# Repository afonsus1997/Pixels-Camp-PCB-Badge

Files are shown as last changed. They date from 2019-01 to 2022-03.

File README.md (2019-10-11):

# Pixels Camp PCB Badge

Working!

## Info
This is a PCB badge for the 2019 edition of pixels camp. The project consists on a 39x9 (351) LED matrix display driven by the IS31FL3741 IC and controlled by an ESP32, making it wifi-connected. The board can be powered by usb and/or a 1s lipo battery (charges with usb).

The main goal is to make a web connected scrolling text display, although anyone can develop a custom version of the firmware.

## Sponsors
ISSI
PCBway

#### PCBWay
PCBWay was kind enough to supply the V2.1 Pcbs and stencils.

#### ISSI
IssI has been a great supporter due to it's technical support and the supplied some samples of the driver IC and the corresponding devboard.

**I thank both of the sponsors for making the new version possible!**

## Updates

### Latest Updates
* New version in development
	* Waiting for the new PCBs and components to arrive 

### Known Bugs
* Waiting for the new version

### TODO
* Assemble new board

## Circuit and PCB

### Circuit

#### Schematics
All Schematics can be found in the PDF folder of the PCB Project
*   [PDFs Folder](https://github.com/afonsus1997/Pixels-Camp-PCB-Badge/tree/master/PCB%20ESP32/PDF)
	* [Control Board Schematic](https://github.com/afonsus1997/Pixels-Camp-PCB-Badge/blob/master/PCB%20ESP32/PDF/CONTROL/Schematic.PDF)   
	* [Matrix Schematic](https://github.com/afonsus1997/Pixels-Camp-PCB-Badge/blob/master/PCB%20ESP32/PDF/MATRIX/Schematic.PDF) 	

#### Power
Power is supplied by usb and/or 1s lipo, with usb charging capabilities.

Circuit

The circuit can be powered by usb and/or 1s lipo. T1 is disabled when usb is present and vice-versa. There is also a main power switch that toggles T2.
An LTSpice simulation is present in the [Simulations](https://github.com/afonsus1997/Pixels-Camp-PCB-Badge/tree/master/PCB%20ESP32/Simulations) folder.

Used ICs:
* Voltage Regulator: NCP708
    * [Datasheet](https://www.onsemi.com/pub/Collateral/NCP708-D.PDF)
* Lipo charger: MCP73831T-2ADI/OT
    * [Datasheet](https://www.sparkfun.com/datasheets/Prototyping/Batteries/MCP73831T.pdf)

#### Digital and logic
The microcontroller used is the ESP32 with WIFI and bluetooth built-in. The LED matrix is driven by the IS31FL3741 IC. The usb to serial conversion in handled by the CH340G (with auto-reset DTR capabilities).

Used ICs:
* uC: ESP32
    * [Datasheet](https://www.espressif.com/sites/default/files/documentation/esp32_datasheet_en.pdf)
* USB-to-Serial: CH340G
    * [Datasheet](https://cdn.sparkfun.com/datasheets/Dev/Arduino/Other/CH340DS1.PDF)
* LED driver: IS31FL3741
    * [Datasheet](http://ams.issi.com/WW/pdf/IS31FL3741.pdf)
    * [Dev Board](http://ams.issi.com/WW/pdf/IS31FL3741_EB.pdf)

### PCBs
The PCBs was designed in Altium Designer and the most recent GERBERs and schematics are available in their respective repo folders. The Badge consists of 2 stackable PCBs, one for the matrix and one for the power and logic. Each PCB is 126x36mm and there is a panel PCB with both of the PCBs held by cuttable tabs. The panel is 140x91mm.

#### IO
Placeholder

#### Renders

##### 2D 
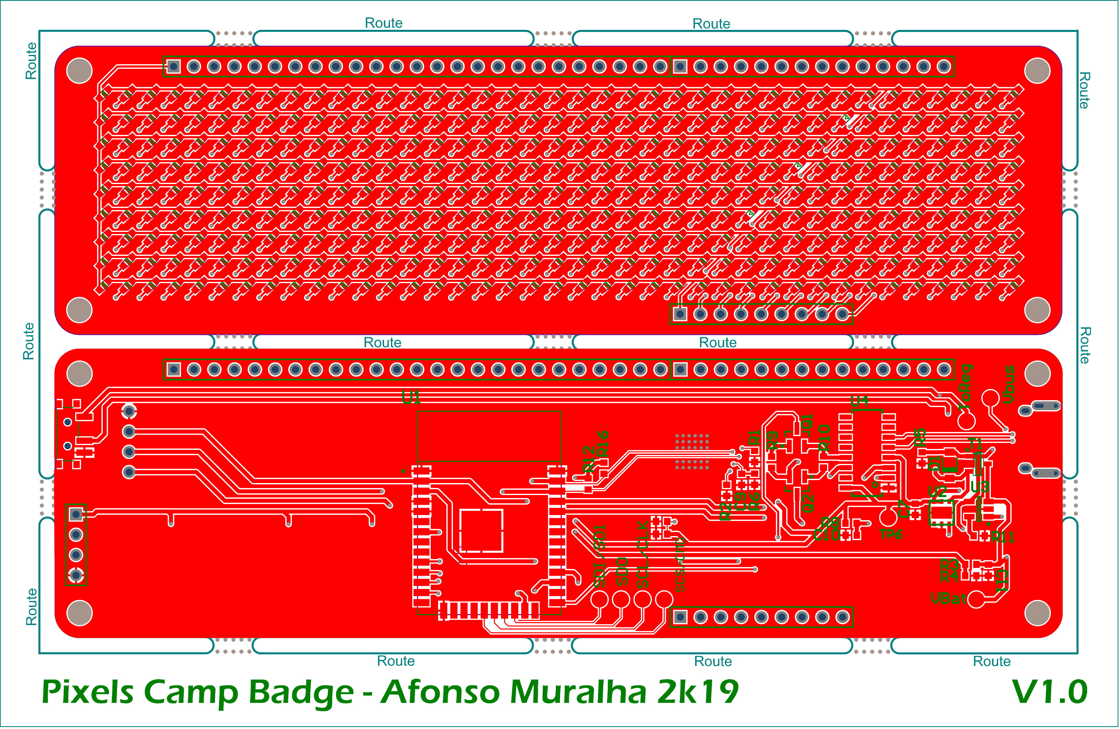
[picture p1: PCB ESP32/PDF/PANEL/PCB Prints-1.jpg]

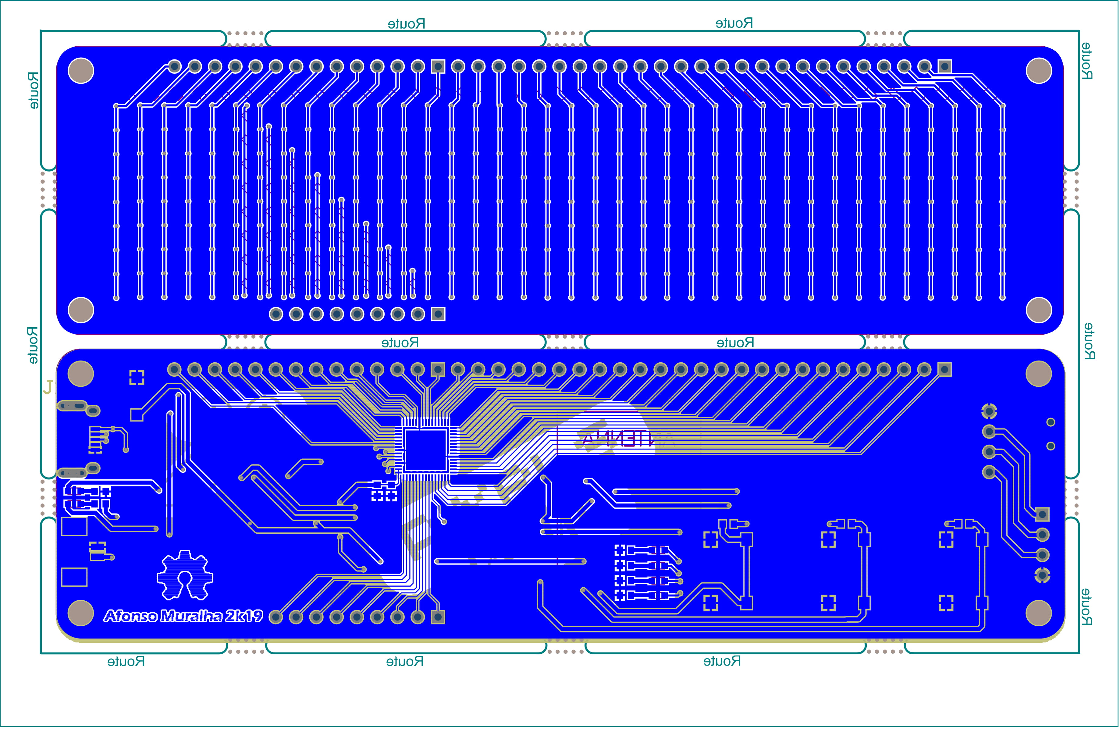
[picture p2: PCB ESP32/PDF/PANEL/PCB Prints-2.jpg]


##### 3D
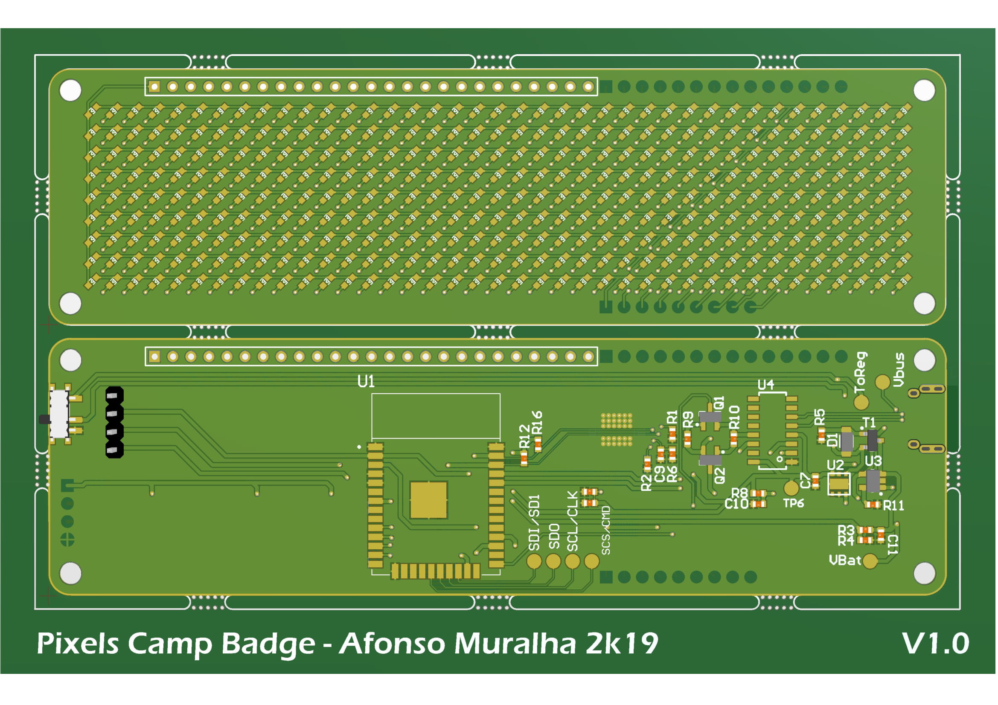
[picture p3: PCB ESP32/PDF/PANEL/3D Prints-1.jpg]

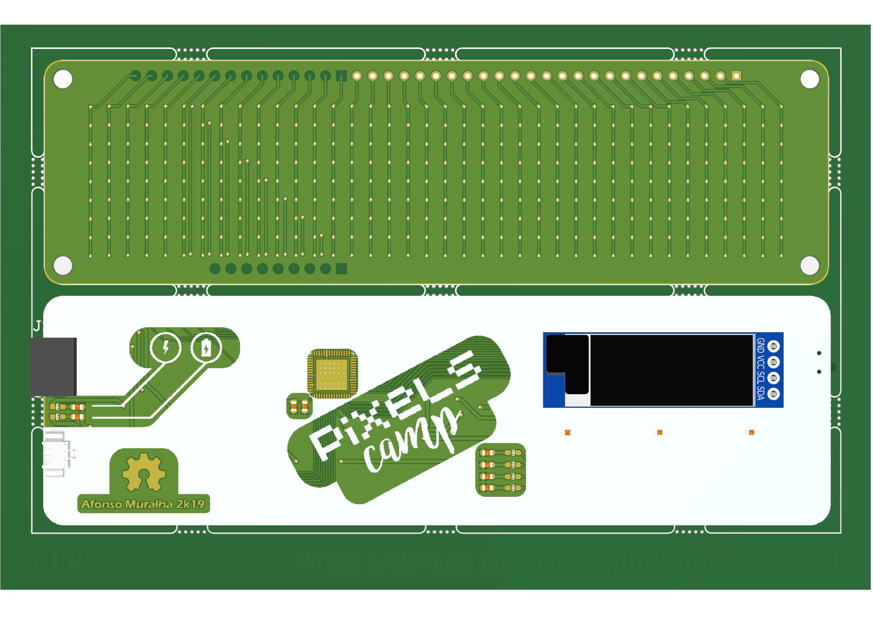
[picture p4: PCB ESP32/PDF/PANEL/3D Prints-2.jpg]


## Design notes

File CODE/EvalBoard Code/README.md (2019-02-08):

# Pixels Camp PCB Badge

## Info
This is a PCB badge for the 2019 edition of pixels camp. The project consists on a 39x9 (351) LED matrix display driven by the IS31FL3741 IC and controlled by an ESP32, making it wifi-connected. The board can be powered by usb and/or a 1s lipo battery (charges with usb).

The main goal is to make a web connected scrolling text display, although anyone can develop a custom version of the firmware.

**Special thanks to ISSI for supporting the project by supplying a devboard for the IS31FL3741 IC, much apreciated!**

## Updates

### Latest Updates
* Working on the firmware (freeRTOS?)
* Working on new control board design

### Known Bugs
* Swapped pins on the regulator footprint
    * Fixed in new version (added an aditional regulator)
* USB-to-Serial (CH340G) needs external oscillator

### TODO
* Fix bugs
* (Add a boot switch for convinience)
* Test LED Matrix with devboard

## Circuit and PCB

### Circuit

#### Power
Power is supplied by usb and/or 1s lipo, with usb charging capabilities.

Circuit

The circuit can be powered by usb and/or 1s lipo. T1 is disabled when usb is present and vice-versa. There is also a main power switch that toggles T2.
An LTSpice simulation is present in the [Simulations](https://github.com/afonsus1997/Pixels-Camp-PCB-Badge/tree/master/PCB%20ESP32/Simulations) folder.

Used ICs:
* Voltage Regulator: NCP708
    * [Datasheet](https://www.onsemi.com/pub/Collateral/NCP708-D.PDF)
* Lipo charger: MCP73831T-2ADI/OT
    * [Datasheet](https://www.sparkfun.com/datasheets/Prototyping/Batteries/MCP73831T.pdf)

#### Digital and logic
The microcontroller used is the ESP32 with WIFI and bluetooth built-in. The LED matrix is driven by the IS31FL3741 IC. The usb to serial conversion in handled by the CH340G (with auto-reset DTR capabilities).

Used ICs:
* uC: ESP32
    * [Datasheet](https://www.espressif.com/sites/default/files/documentation/esp32_datasheet_en.pdf)
* USB-to-Serial: CH340G
    * [Datasheet](https://cdn.sparkfun.com/datasheets/Dev/Arduino/Other/CH340DS1.PDF)
* LED driver: IS31FL3741
    * [Datasheet](http://ams.issi.com/WW/pdf/IS31FL3741.pdf)
    * [Dev Board](http://ams.issi.com/WW/pdf/IS31FL3741_EB.pdf)

### PCBs
The PCBs was designed in Altium Designer and the most recent GERBERs and schematics are available in their respective repo folders. The Badge consists of 2 stackable PCBs, one for the matrix and one for the power and logic. Each PCB is 126x36mm and there is a panel PCB with both of the PCBs held by cuttable tabs. The panel is 140x91mm.

#### IO
Placeholder

#### Renders

##### 2D 
TOP
BOT

##### 3D
TOP
BOT

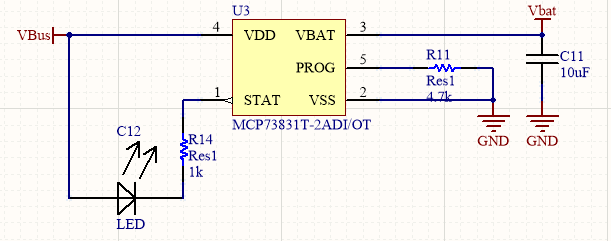
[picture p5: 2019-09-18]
Blog Writeup/Pictures/chargingschematic.PNG

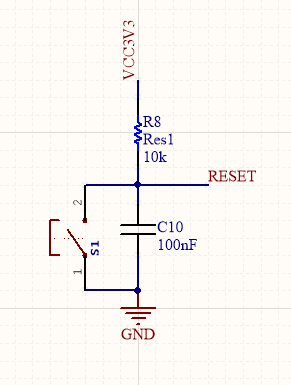
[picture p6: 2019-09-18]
Blog Writeup/Pictures/esp32reset_schematic.PNG

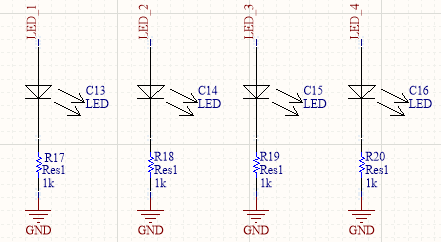
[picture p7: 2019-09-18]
Blog Writeup/Pictures/esp32led_schematic.PNG

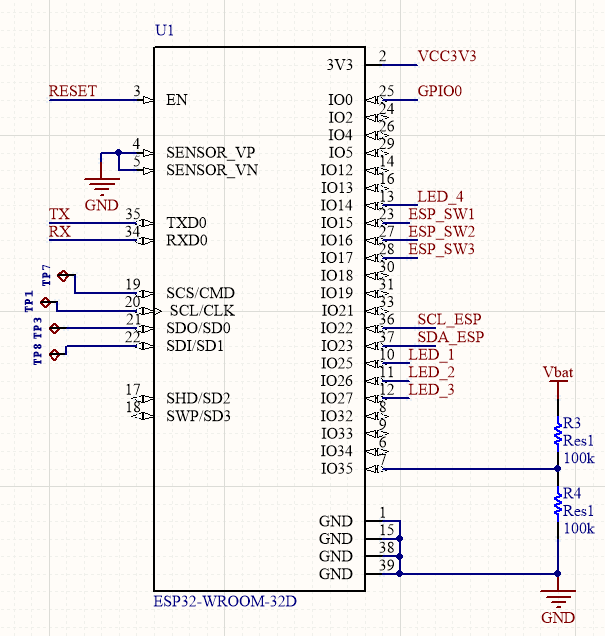
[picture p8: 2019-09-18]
Blog Writeup/Pictures/esp32_schematic.PNG

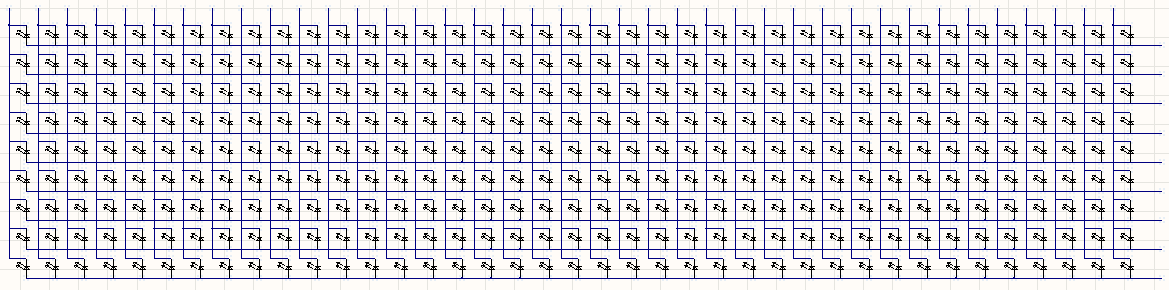
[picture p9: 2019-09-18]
Blog Writeup/Pictures/Ledmatrix_schematicc.PNG

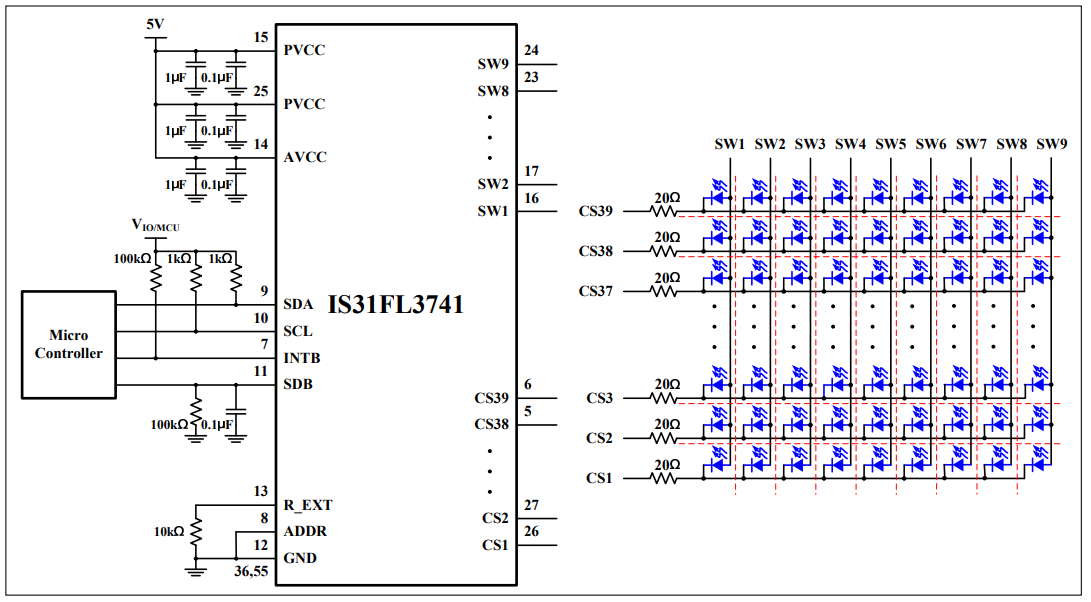
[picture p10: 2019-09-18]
Blog Writeup/Pictures/issisamplecircuit.PNG

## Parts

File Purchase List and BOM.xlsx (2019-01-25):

Purchase List |  |  |  |  |  | BOM
PCB
Product | Store | Quantity |  |  | Price
PCB Panel | JLC PCB | 5 |  |  | 20.76
Total |  |  |  |  | 20.76
Components |  |  |  |  |  | Components
Product | Store | Quantity | Used | Remaining | Price | Component type | Product | Available | Required | Price per part | Price
MMBT2222A-7-F (NPN Transistor) | Arrow | 6 | 0 | 6 | 0.58 | NPN Transistor | MMBT2222A | 6 | 2 | 0.09666666667 | 0.1933333333
NCP708MU330TAG (3v3 Regulator) | Arrow | 5 | 1 | 4 | 1.74 | 3.3V Regulator | NCP708MU330TAG | 4 | 1 | 0.348 | 0.348
B5818W (schottky diode) | Arrow | 5 | 0 | 5 | 0.36 | Schottky Diode |  | 105 | 1
MCP73831T (lipo charger) | Arrow | 2 | 0 | 2 | 0.89 |  | B5818W | 5 |  | 0.072 | 0.072
 | Ali | 10 | 0 | 10 | 1 |  | IN5817 | 100 |  | 0.0094 | 0.0094
DMP2045U (p-channel mosfet) | Arrow | 2 | 0 | 2 | 0.68 | Lipo Charger | MCP73831T | 12 | 1 | 0.1 | 0.1
532610271 (lipo connector) | Arrow | 2 | 0 | 2 | 1.4 | P-channel MOSFET |  | 72 | 1
 | Ali | 10 | 0 | 10 | 0.7 |  | DMP2045U | 2 |  | 0.34 | 0.34
tax | Arrow | 1 | 0 | 1 | 1.19 |  | AO3407 | 50 |  | 0.0212 | 0.0212
IS31FL3741-QFLS4-TR (LED driver) | Arrow | 2 | 0 | 2 | 4.8 |  | DMG3415U | 20 |  | 0.0925 | 0.0925
1054431101 (USB connector) | Arrow | 2 | 0 | 2 | 1.48 | Lipo Connector | 532610271 | 12 | 1 | 0.07 | 0.07
tax | Arrow | 1 | 0 | 1 | 1.01 | LED Driver | IS31FL3741 | 2 | 1 | 2.4 | 2.4
AO3407 (p-channel mosfet) | Ali | 50 | 0 | 50 | 1.06 | USB Connector | USB connector 1 | 20 | 1 | 0.035 | 0.035
DMG3415U (p-channel mosfet) | Ali | 20 | 0 | 20 | 1.85 | Green LED | 0603 LED | 1000 | 351 | 0.00396 | 1.38996
IN5817 (schottky diode) | Ali | 100 | 0 | 100 | 0.94 | ESP32 | ESP32 | 3 | 1 | 3.333333333 | 3.333333333
Green LED | Ali | 1000 | 0 | 1000 | 3.96 | Lipo Cable | Lipo Cable | 10 | 1 | 0.088 | 0.088
ESP32 | Ali | 3 | 0 | 3 | 10 | USB to Serial | CH340G | 5 | 1 | 0.268 | 0.268
Lipo Cable | Ali | 10 | 0 | 10 | 0.88 | Push Button | Push Button | 50 | 3 | 0.015 | 0.045
CH340G (USB to Serial) | Ali | 5 | 0 | 5 | 1.34 | PCB | PCB | 5 | 1 | 4.152 | 4.152
Push button | Ali | 50 | 0 | 50 | 0.75
USB connector 1 | Ali | 20 | 0 | 20 | 0.7 | Total |  |  |  |  | 12.35322667
USB connector 2 | Ali | 10 | 0 | 10 | 0.5
Total |  |  |  |  | 37.81
Total (all) |  |  |  |  | 58.57

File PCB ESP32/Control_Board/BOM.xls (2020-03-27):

Comment | Value | Description | Designator | Footprint | LibRef | Quantity
Footprint of the VIMEX MSK-12C02 SPDT SMD Switch Created by mzst on 17-Jan-2016 |  |  | 1 | MSK-12C02 | MSK-12C02_SMD_SPDT_SWITCH | 1
AMS1117 |  | LDO 3.3V/5V/12V | AMS1 | SOT-223-3 | AMS1117 | 1
10uF |  |  | C1, C3, C13 | C 0603 / 1608 | Capacitor | 3
1uF |  |  | C2, C4, C6, C8 | C 0603 / 1608 | Capacitor | 4
0.1uF |  |  | C5, C7, C11 | C 0603 / 1608 | Capacitor | 3
22uF |  |  | C9 | C 0603 / 1608 | Capacitor | 1
LED |  |  | C10, C14, C15, C16, C17, C18 | LED 0603(2) | LED | 6
100nF |  |  | C12 | C 0603 / 1608 | Capacitor | 1
Diode_Littelfuse_SP0503BAHTG_eec |  | DIODE TVS DIODE 5.5VWM 8.5VC SOT143 | D1 | Littelfuse_SP0503BAHTG_0 | Diode_Littelfuse_SP0503BAHTG_eec | 1
B5819W |  | Schottky Barrier Rectifier, 1 A, 40 Vrm, -65 to 125 degC, 2-Pin SOD123, RoHS, Tape and Reel | D2, D3 | MCC-SOD123_V | CMP-2100-03587-1 | 2
MicroUsb |  | 10103594-0001LF Conn Micro USB Type B RCP 5 POS 0.65mm Solder RA SMD 5 Terminal 1 Port T/R | J1 | USB-MicroB | MicroUsb | 1
53261-0271 |  | PicoBlade(TM) Header, Right Angle, -40 to 85 degC, 2-Pin SMD, RoHS, Tape and Reel | P1 | MOLX-53261-0271_V | CMP-2000-05633-1 | 1
Header 5X2 |  | Header, 5-Pin, Dual row | P2 | 5x2_SidePCB | Header 5X2 | 1
Header 3X2 |  | Header, 3-Pin, Dual row | P3 | 3x2_SidePCB | Header 3X2 | 1
Header 25 |  | Header, 25-Pin | P4 | HDR1X25 | Header 25 | 1
Header 4 |  | Header, 4-Pin | P5 | HDR1X4 | Header 4 | 1
Header 14 |  | Header, 14-Pin | P6 | HDR1X14 | Header 14 | 1
Header 9 |  | Header, 9-Pin | P7 | HDR1X9 | Header 9 | 1
MMBT2222LT1G |  | General Purpose Transistor, NPN, 0.6 A IC Continuous, 3-Pin SOT23, RoHS, Tape and Reel | Q1, Q2 | ONSC-SOT-23-3-318-08_M | CMP-0722-00001-1 | 2
Res1 | OPEN | Resistor | R1, R2, R5, R8, R10, R17, R30, R32 | C 0603 / 1608 | Res1 | 8
Res1 | 470 | Resistor | R3, R4 | C 0603 / 1608 | Res1 | 2
Res1 | 100k | Resistor | R6, R7, R9, R16 | C 0603 / 1608 | Res1 | 4
Res1 | 10k | Resistor | R11, R12, R13, R15, R18, R21, R22, R23 | C 0603 / 1608 | Res1 | 8
Res1 | 1k | Resistor | R14, R20, R26, R27, R28, R29 | C 0603 / 1608 | Res1 | 6
Res1 | 4.7k | Resistor | R19, R24, R25, R31 | C 0603 / 1608 | Res1 | 4
742C083121JP |  | Res Thick Film Array 120 Ohm 5% 1/4W Â±200ppm/Â°C ISOL Molded 8-Pin 1206_4 X 0603_ Concave SMD Paper T/R | RN1, RN2, RN3, RN4, RN5, RN6, RN7, RN8, RN9, RN10 | RESARRAY(4x0603) | Resistor Array 4x | 10
Switch |  |  | S1 | PUSH_SMD_3x4 | B3U-1000P | 1
DTSM-6 |  |  | S2, S3, S4 | DTSM-6 | DTSM-6 | 3
DMP2045U |  | P-CHANNEL MOSFET WITH DIODE | T1, T2 | SOT95P237X112-3N | Si2333CDS-T1-GE3 | 2
Test pad |  |  | ToReg1, TP1, VBat1, VBus1 | TP20R | TPTP20R | 4
ESP32-WROOM-32D |  | IC: SoC; GPIO, I2C, I2S, IR, SD, SDIO, SPI, UART; 2.7Ã·3.6VDC; 20dBm | U1 | MODULE_ESP32-WROOM-32D | ESP32-WROOM-32D | 1
CP2102-GM | Value | No Description Available | U2 | QFN28_5X5 | CP2102-GM | 1
IS31FL3741 |  |  | U3 | QFN40P700X700X80-61N | IS31FL3741 | 1
MCP73831T-2ADI/OT |  | Miniature Single-Cell, Fully Integrated Li-Ion, Li-Polymer Charge Management Controller, 4.2V, 5-Pin SOT-23, Industrial Temperature, Tape and Reel | U4 | SOT-23-OT5_M | CMP-0133-00142-1 | 1

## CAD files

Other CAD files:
PCB ESP32/Media/Control/bot_silkV2.dxf

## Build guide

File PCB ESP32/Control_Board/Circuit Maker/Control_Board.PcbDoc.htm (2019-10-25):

Reporting Options

# File in Previous Format

Date | : | 19/10/2019
Time | : | 12:14:36
Filename | : | F:\Documents\GitHub\0603-Led-Matrix\PCB ESP32\Control_Board\Circuit Maker\Control_Board.PcbDoc

Version | Warning
6.3 | CAUTION - Via connections to both hatched and solid signal layer polygons are now controlled by the polygon connect style rule. Re-pouring polygons may result in physical copper differences.
Summer 09 | CAUTION - File contains old violation objects. These violations are no longer supported & will not be loaded. Please run DRC after opening this file in order to refresh the violations.
Summer 09 | CAUTION - Existing testpoint rules and settings are used as fabrication testpoint information.
Altium Designer update 19 | CAUTION - Air Gap Width attribute was introduced to Polygon Connect Style Rule. Air Gap Width attribute now controls the distance between poured polygon and pads on the same net - this value was previosuly taken from clearance rule while ignoring net subscope leading to sometime unexpected results.
Release 13 | CAUTION - Silkscreen Over Component Pads Rules are converted to Silk To Solder Mask Clearance Rules. Suggest examining rule scopes for accuracy.
Release 14 | CAUTION - The Differential Pairs Routing rule added support for control of the width. Be aware that Width rules pertaining to differential pairs need to be manually moved to the Differential Pairs Routing rule.

This file was generated by an earlier version of the software

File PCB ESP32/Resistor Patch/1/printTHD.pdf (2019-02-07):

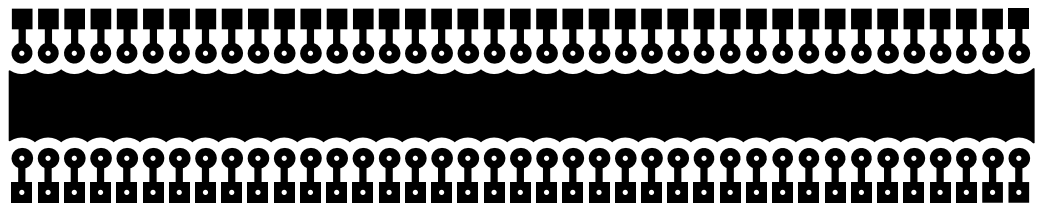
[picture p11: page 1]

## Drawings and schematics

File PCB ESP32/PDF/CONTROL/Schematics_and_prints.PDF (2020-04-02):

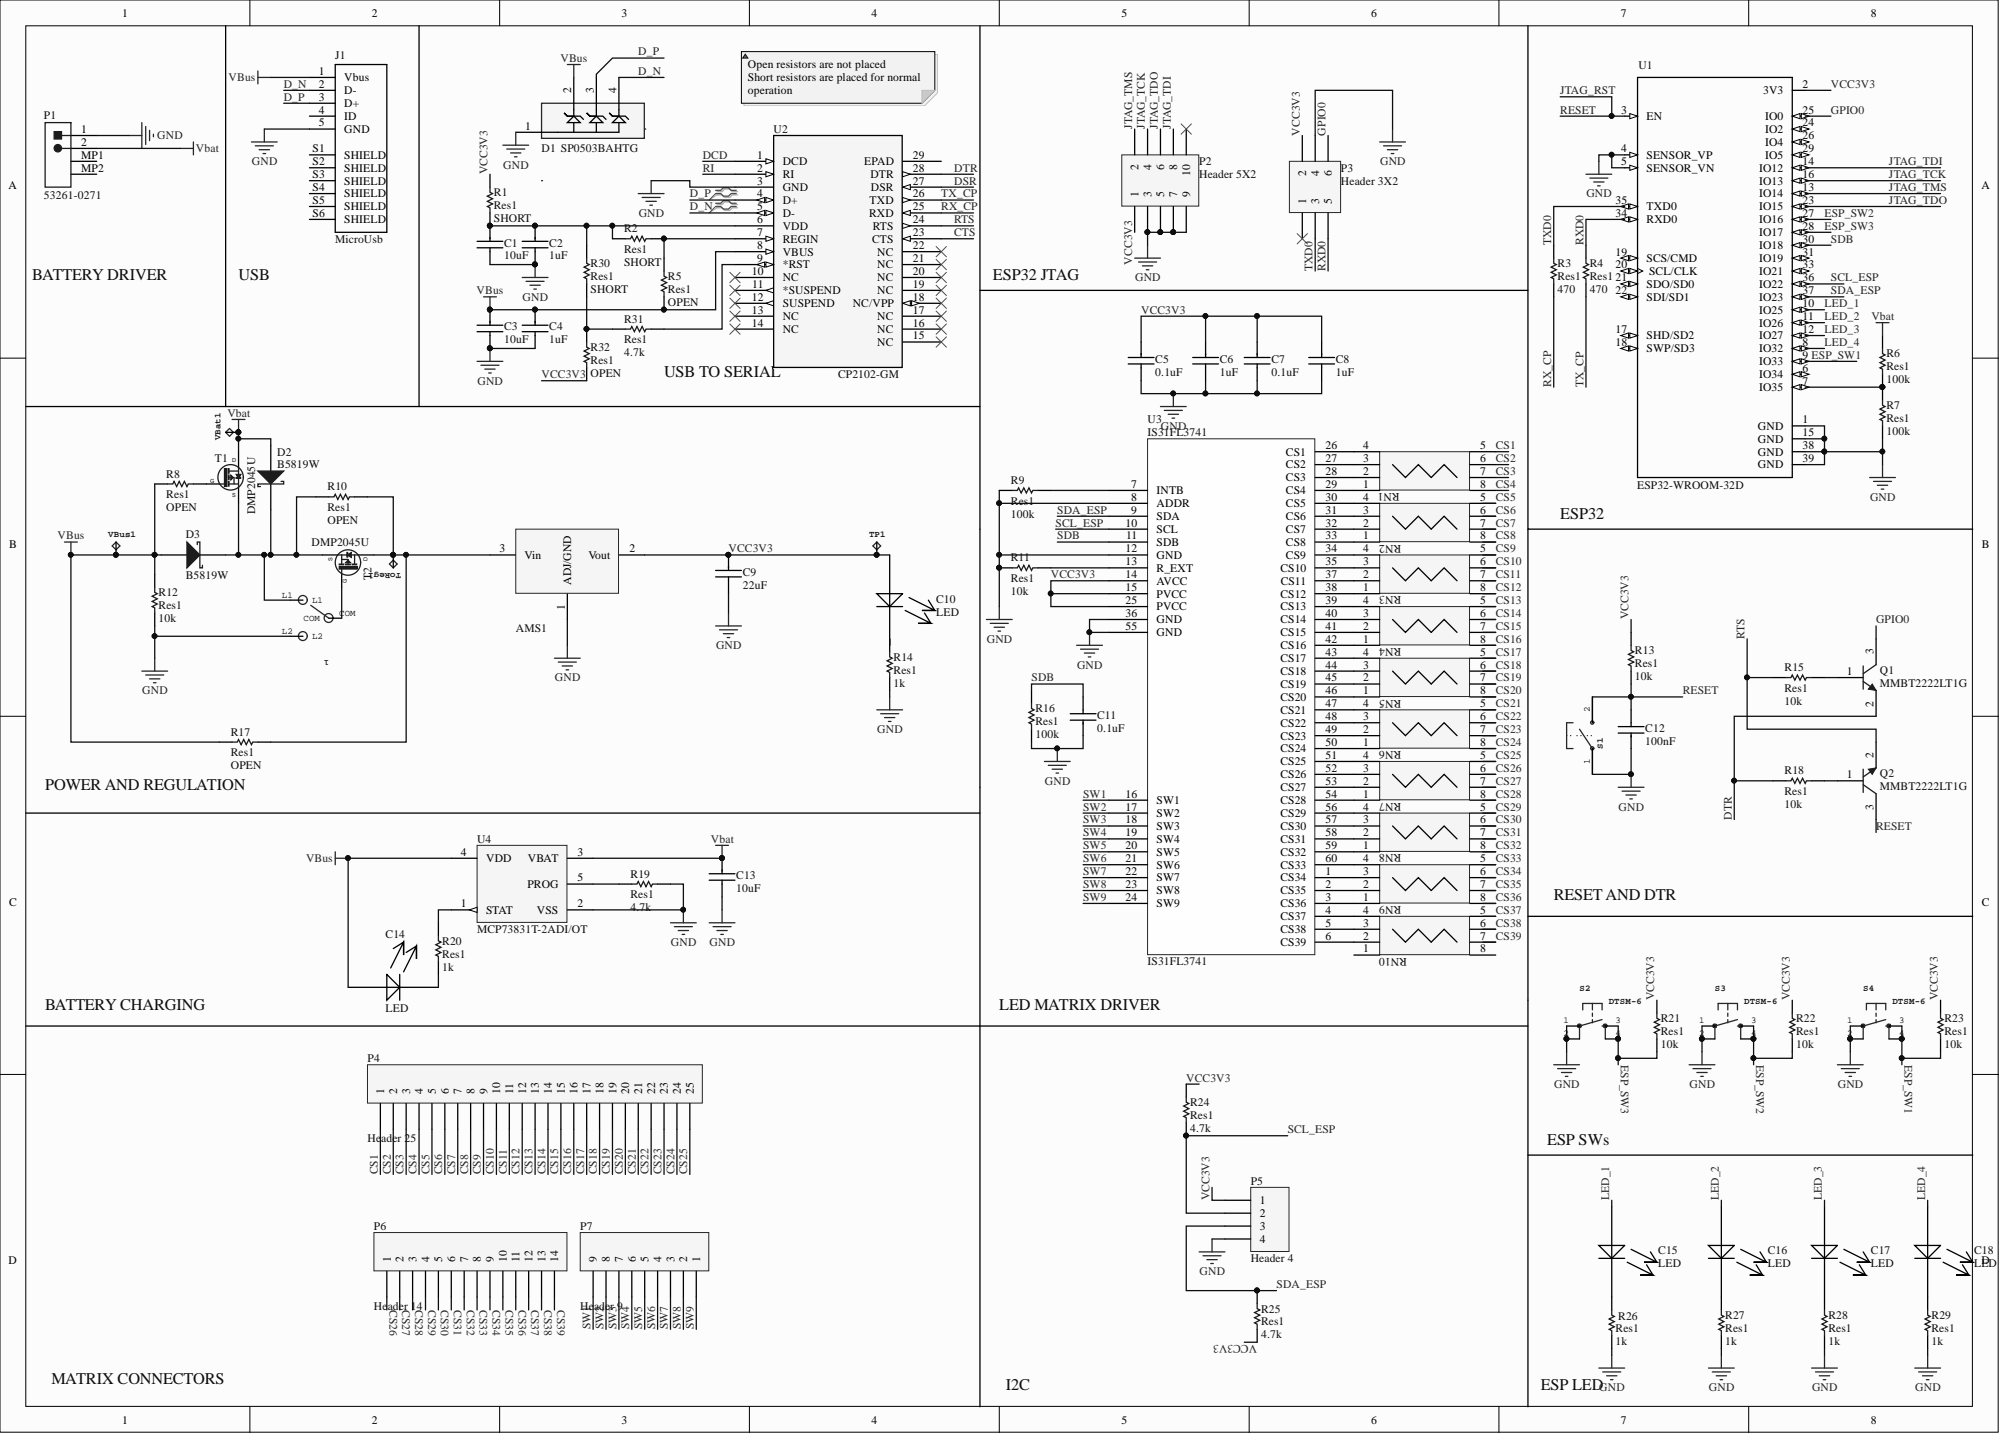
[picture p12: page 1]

Open resistors are not placed
Short resistors are placed for normal
operation

REGIN 7
VBUS 8
*RST 9

R5 Res1 OPEN | | NC 10

PVCC 15 | 1 | | 8
PVCC 25 | 5

SDB | GND 36 | 3 | | 6

GND 55 | 2 | | 7

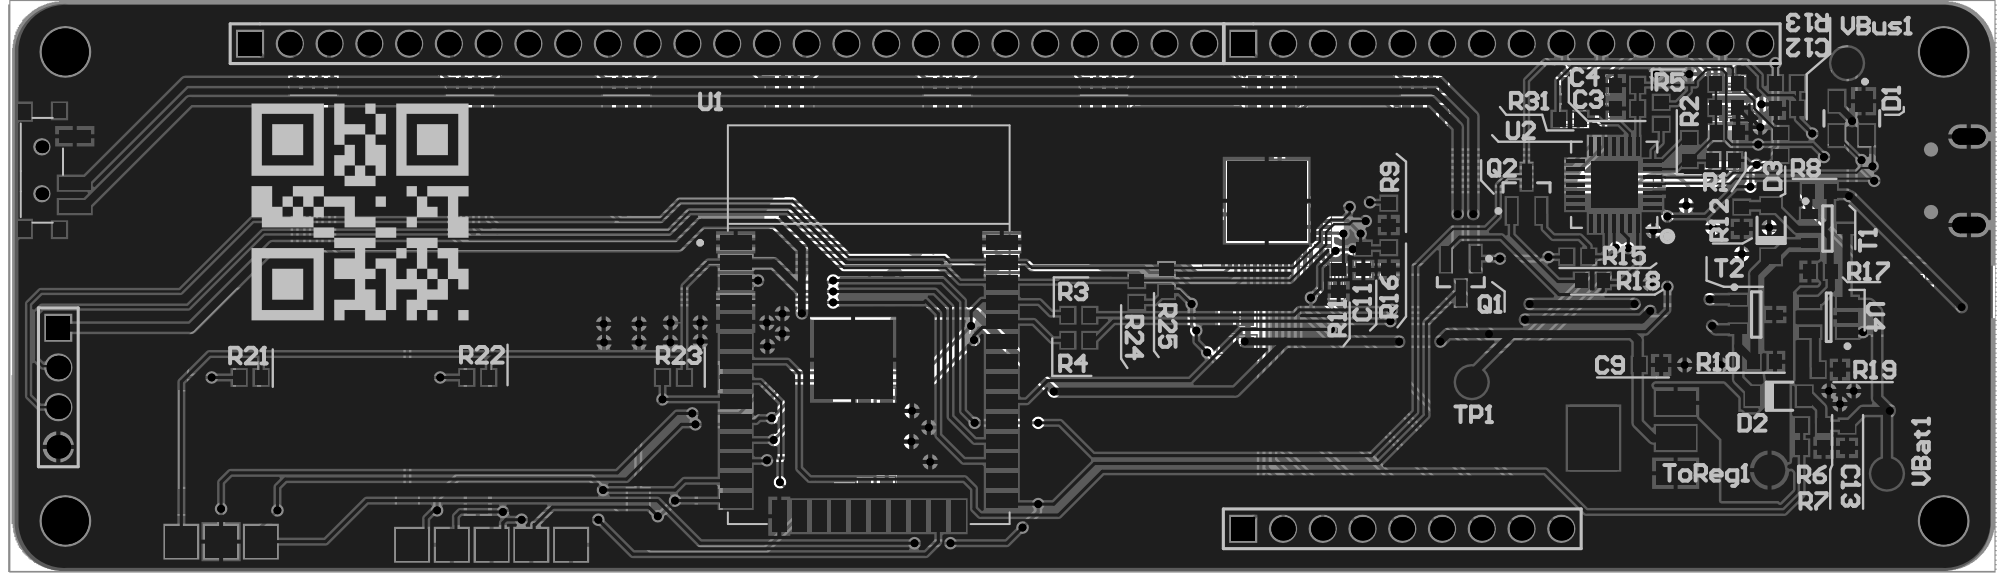
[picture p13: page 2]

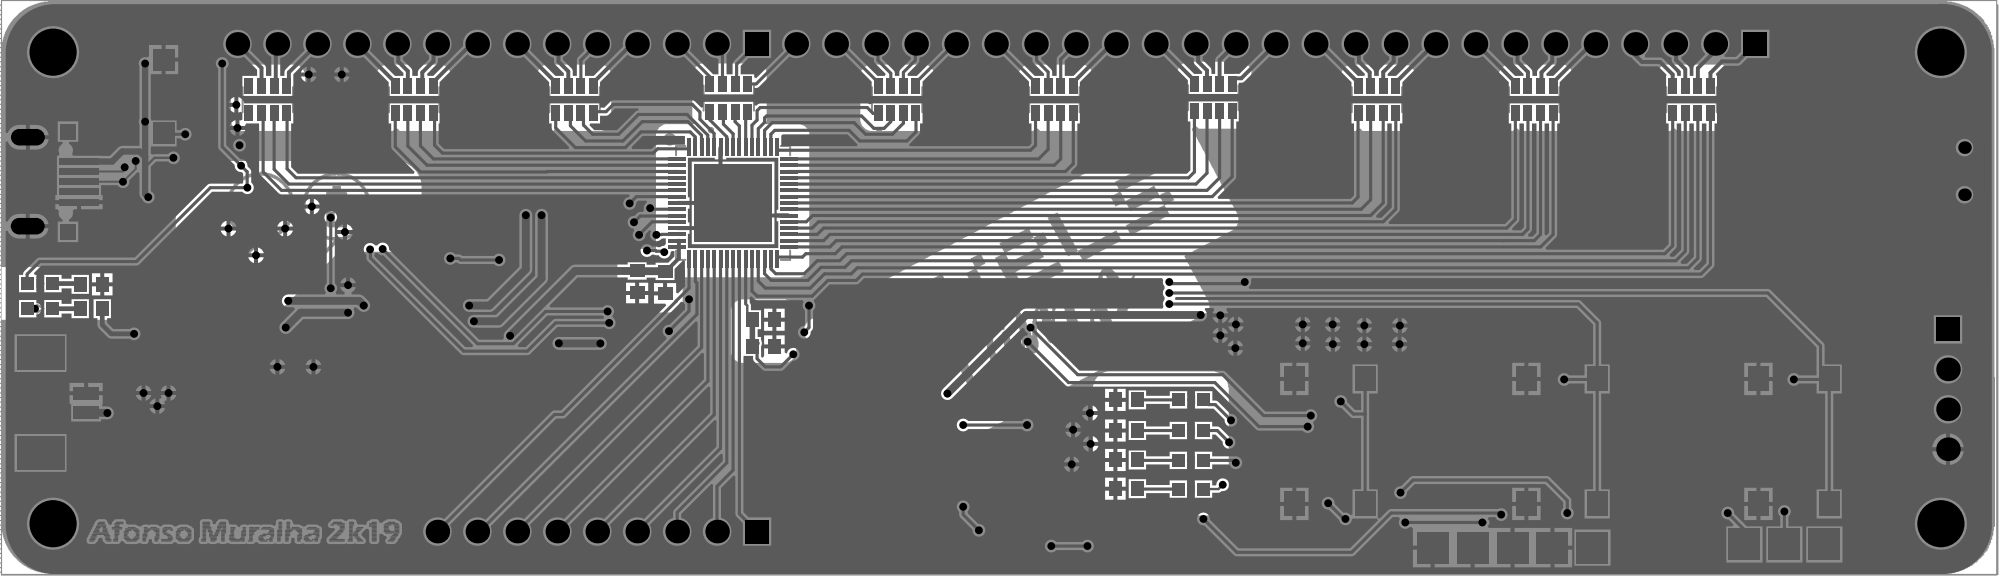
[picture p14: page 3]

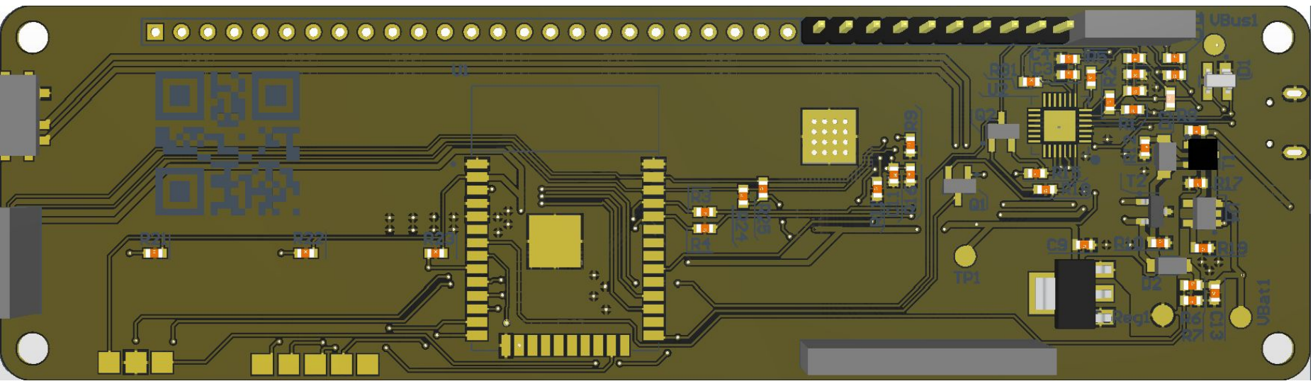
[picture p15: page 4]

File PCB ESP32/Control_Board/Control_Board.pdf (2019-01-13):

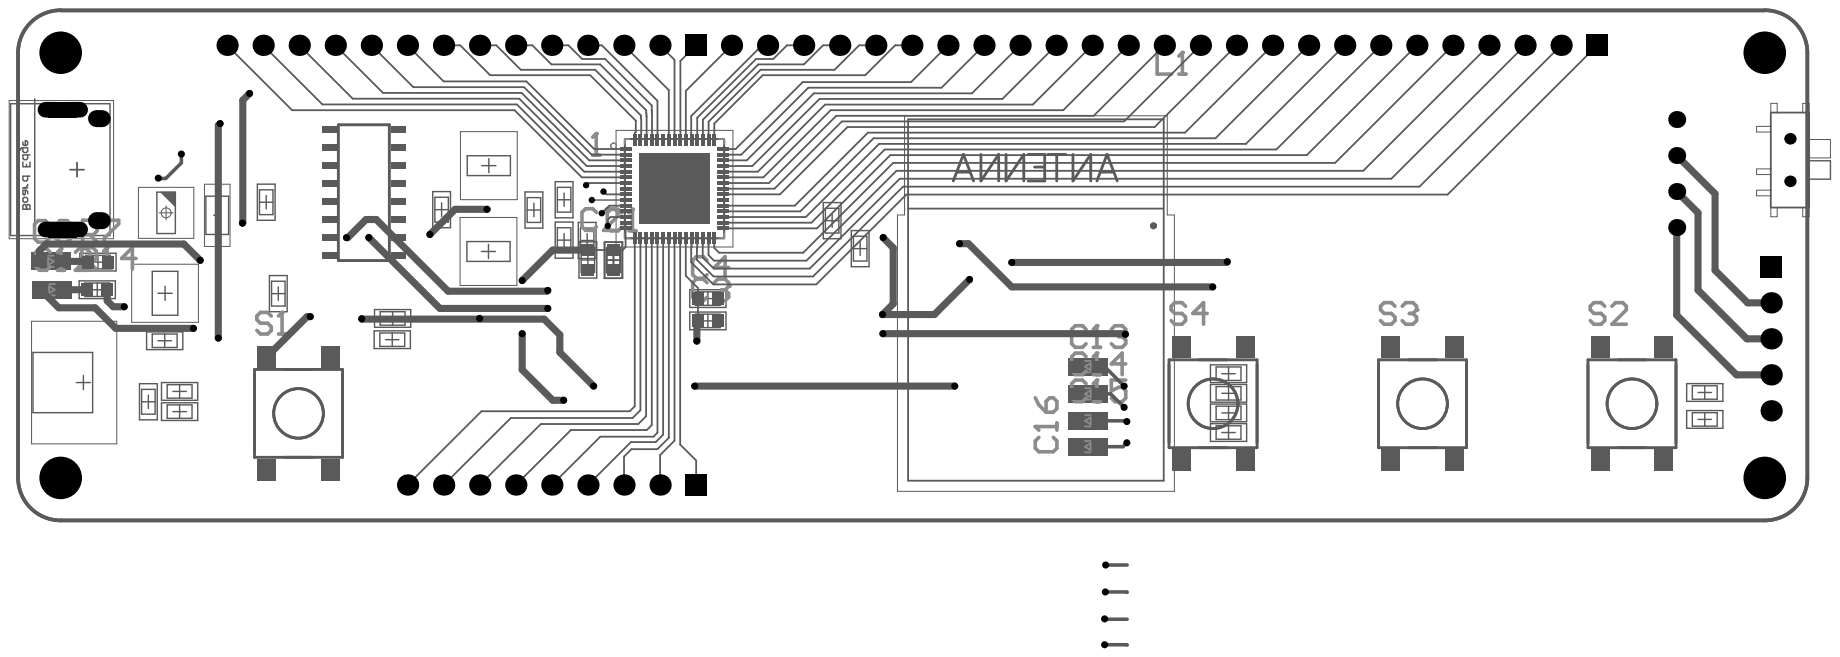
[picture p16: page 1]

Comment | Description | Designator | Footprint | LibRef | Quantity
IS31FL3741 | | 1 | QFN40P700X700X80-61N | IS31FL3741 | 1
CH340G | | 2 | SOIC16 | CH340G | 1
Footprint of the VIMEX MSK-12C02 SPDT SMD Switch Created by mzst on 17-Jan-2016 | | 3 | MSK-12C02 | MSK-12C02_SMD_SPDT_SWIT CH | 1
0.1uF | | C1, C3, C9 | C 0603 / 1608 | Capacitor | 3
1uF | | C2, C4 | C 0603 / 1608 | Capacitor | 2
22uF | | C7 | C 0603 / 1608 | Capacitor | 1
LED | | C8, C12, C13, C14, C15, C16 | LED 0603(2) | LED | 6
Capacitor | | C10 | C 0603 / 1608 | Capacitor | 1
10uF | | C11 | C 0603 / 1608 | Capacitor | 1
B5819W | Schottky Barrier Rectifier, 1 A, 40 Vrm, -65 to 125 degC, 2-Pin SOD123, RoHS, Tape and Reel | D1 | MCC-SOD123_V | CMP-2100-03587-1 | 1
105443-1101 | Micro B Receptacle Connector, 30 V, 1 A, -30 to 85 degC, RoHS | J1 | MOLX-105443-1101_V | CMP-2000-07437-1 | 1
OLED I2C 0.96' 128X64 | | L1 | OLED I2C 0.91 | OLED I2C 0.96' 128X64 | 1
53261-0271 | PicoBlade(TM) Header, Right Angle, -40 to 85 degC, 2-Pin SMD, RoHS, Tape and Reel | P1 | MOLX-53261-0271_V | CMP-2000-05633-1 | 1
Header 5 | Header, 5-Pin | P2 | HDR1X5 | Header 5 | 1
Header 25 | Header, 25-Pin | P3 | HDR1X25 | Header 25 | 1
Header 14 | Header, 14-Pin | P4 | HDR1X14 | Header 14 | 1
Header 9 | Header, 9-Pin | P5 | HDR1X9 | Header 9 | 1
MMBT2222LT1G | General Purpose Transistor, NPN, 0.6 A IC Continuous, 3-Pin SOT23, RoHS, Tape and Reel | Q1, Q2 | ONSC-SOT-23-3-318-08_M | CMP-0722-00001-1 | 2
Res1 | Resistor | R1, R2, R3, R4, R5, R6, R7, R8, R9, R10, R11, R12, R13, R14, R15, R16, R17, R18, R19, R20 | C 0603 / 1608 | Res1 | 20
DTSM-6 | | S1, S2, S3, S4 | DTSM-6 | DTSM-6 | 4
DMP2045U | P-CHANNEL MOSFET WITH DIODE | T1 | SOT95P237X112-3N | Si2333CDS-T1-GE3 | 1
ESP32-WROOM-32D | IC: SoC; GPIO, I2C, I2S, IR, SD, SDIO, SPI, UART; 2.7Ã·3.6VDC; 20dBm | U1 | MODULE_ESP32-WROOM-32D | ESP32-WROOM-32D | 1
NCP708 | | U2 | UDFN6 CASE 517DD | NCP708 | 1
MCP73831T-2ADI/OT | Miniature Single-Cell, Fully Integrated Li-Ion, Li-Polymer Charge Management Controller, 4.2V, 5-Pin SOT-23, Industrial Temperature, Tape and Reel | U3 | SOT-23-OT5_M | CMP-0133-00142-1 | 1

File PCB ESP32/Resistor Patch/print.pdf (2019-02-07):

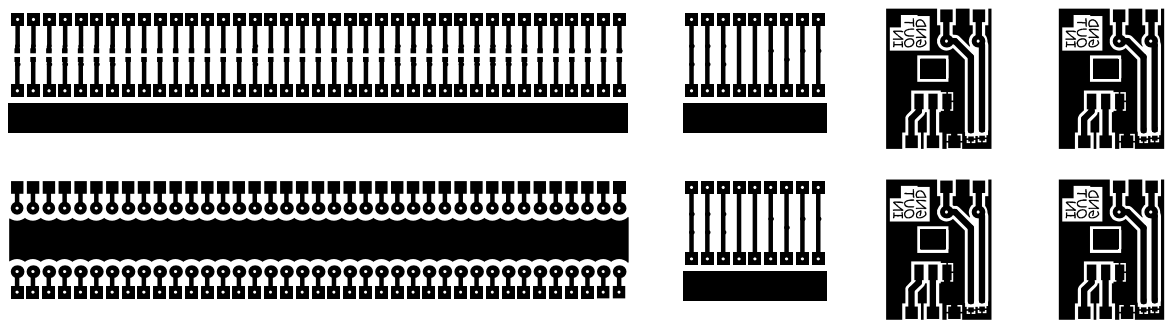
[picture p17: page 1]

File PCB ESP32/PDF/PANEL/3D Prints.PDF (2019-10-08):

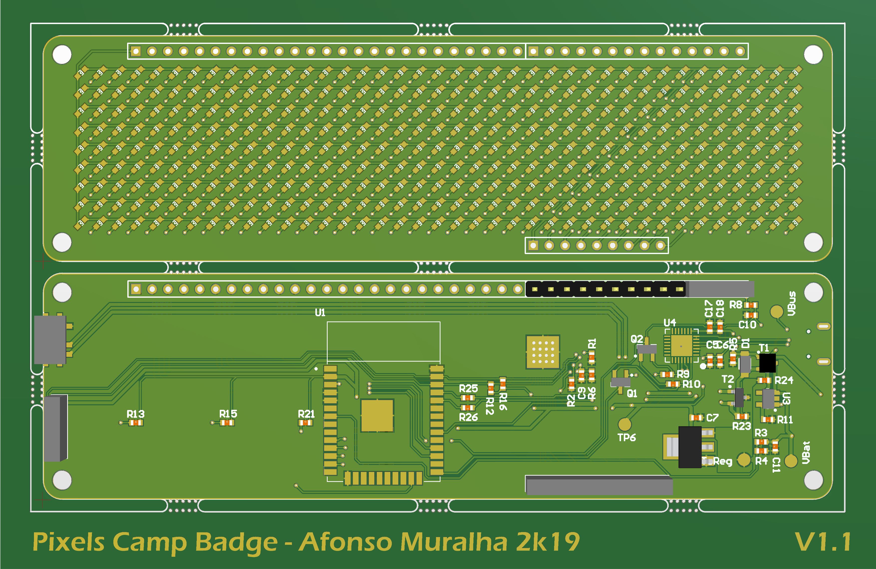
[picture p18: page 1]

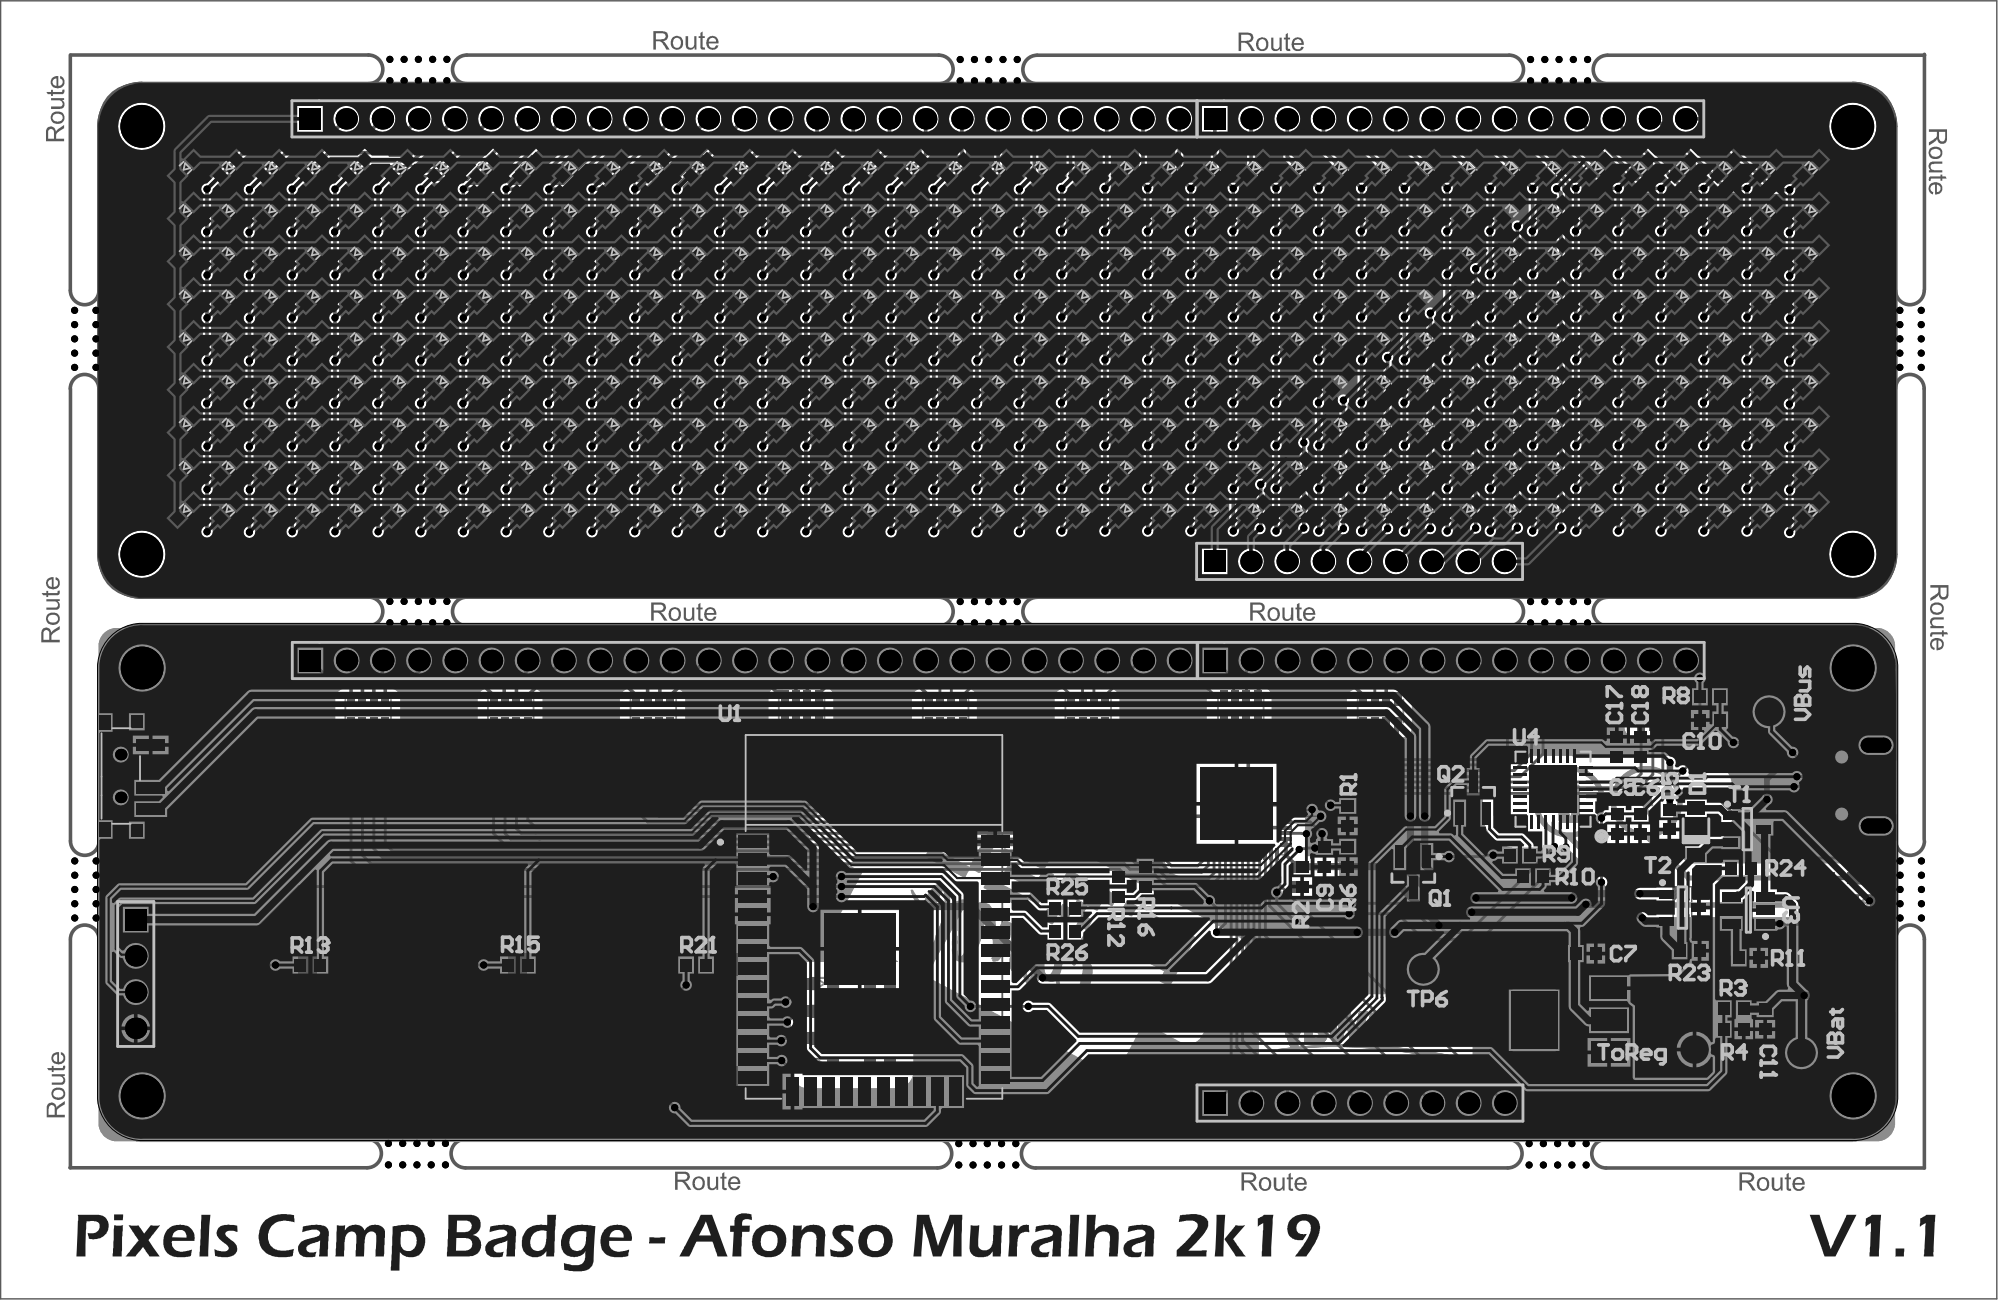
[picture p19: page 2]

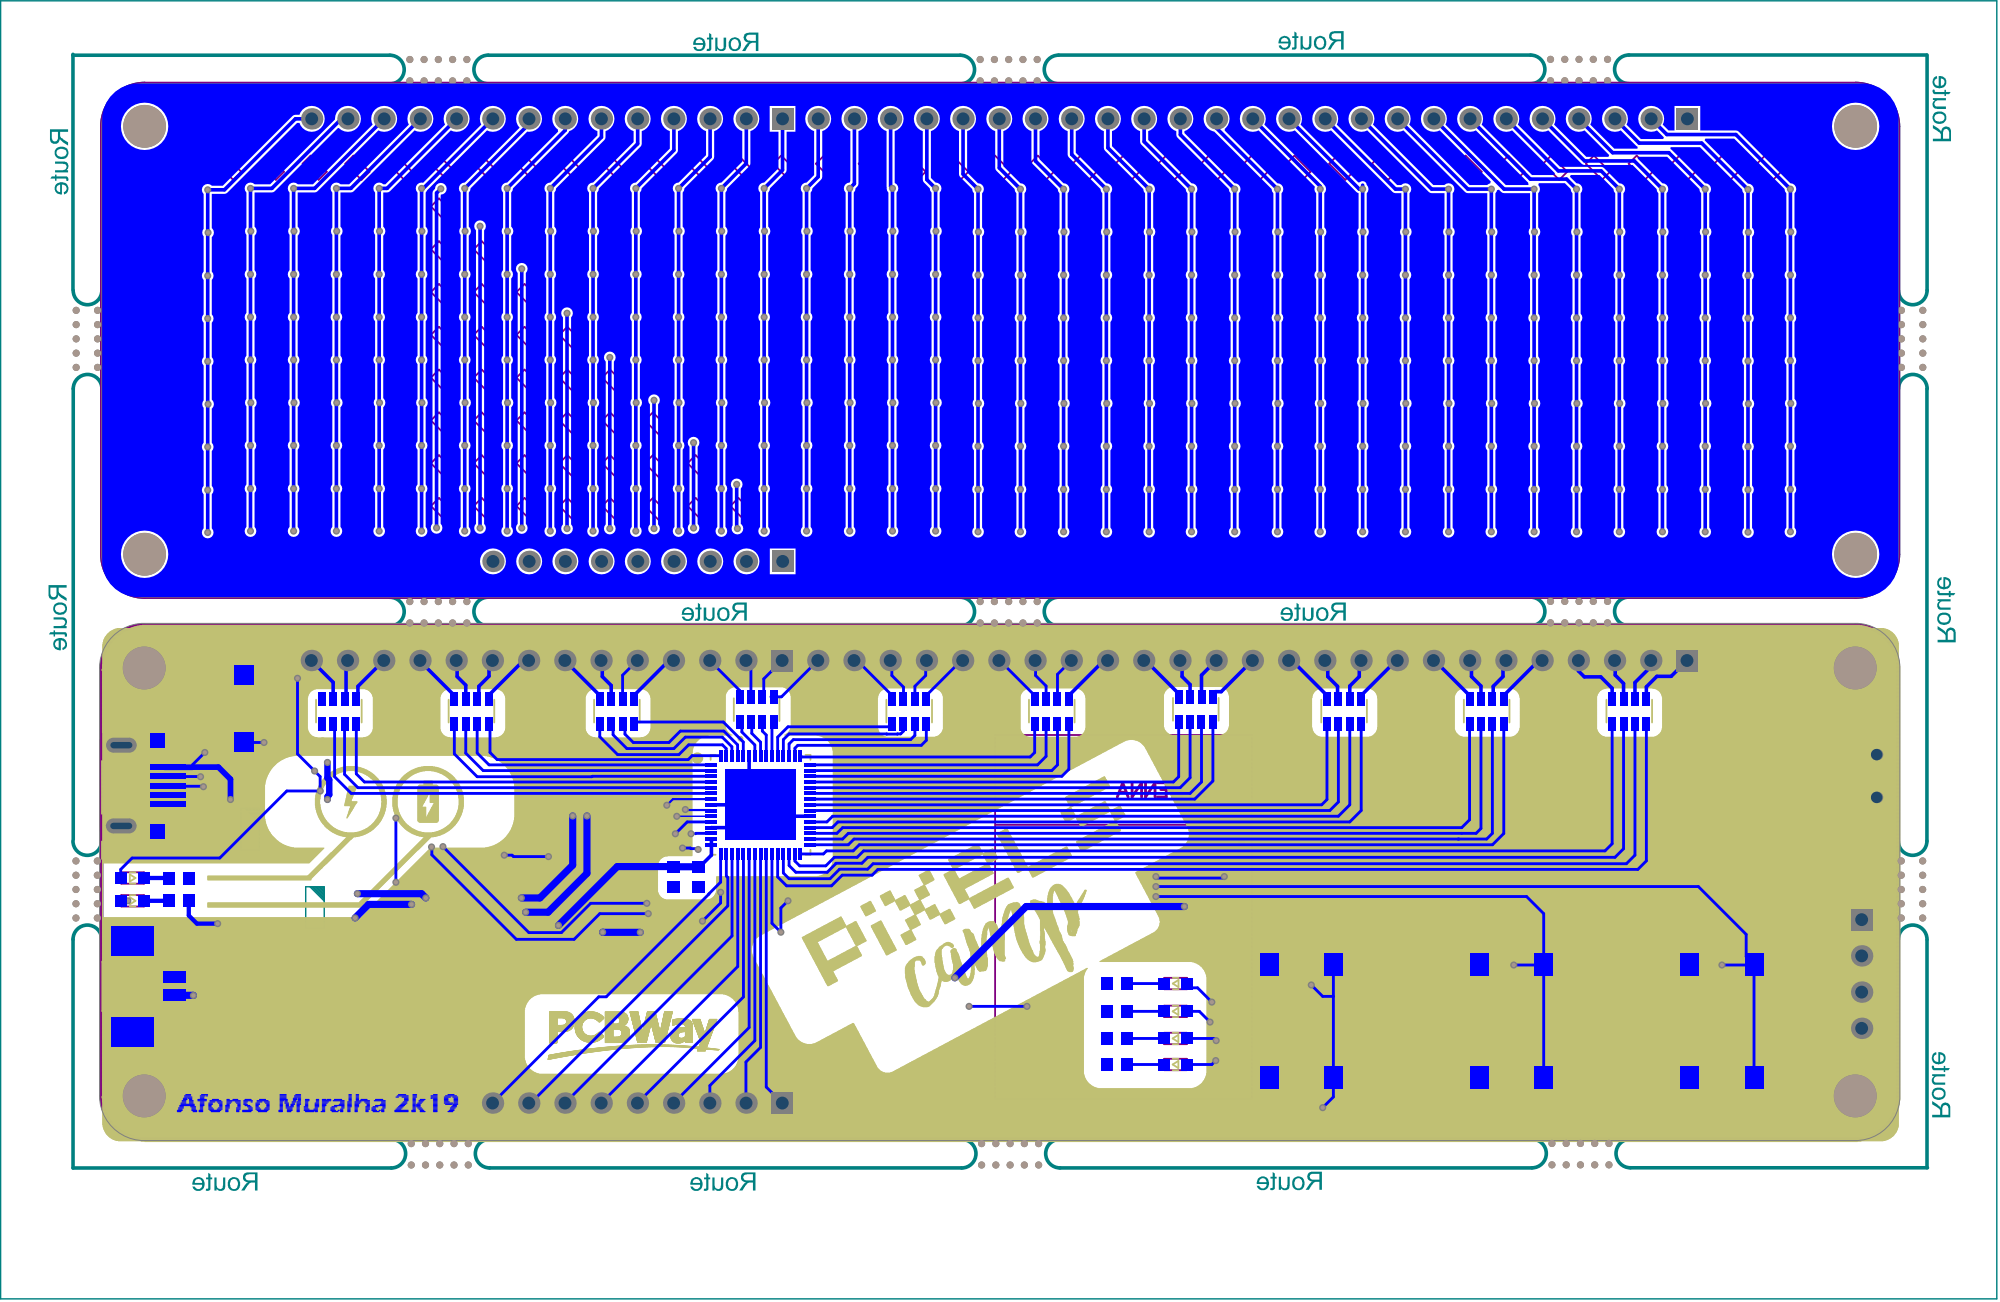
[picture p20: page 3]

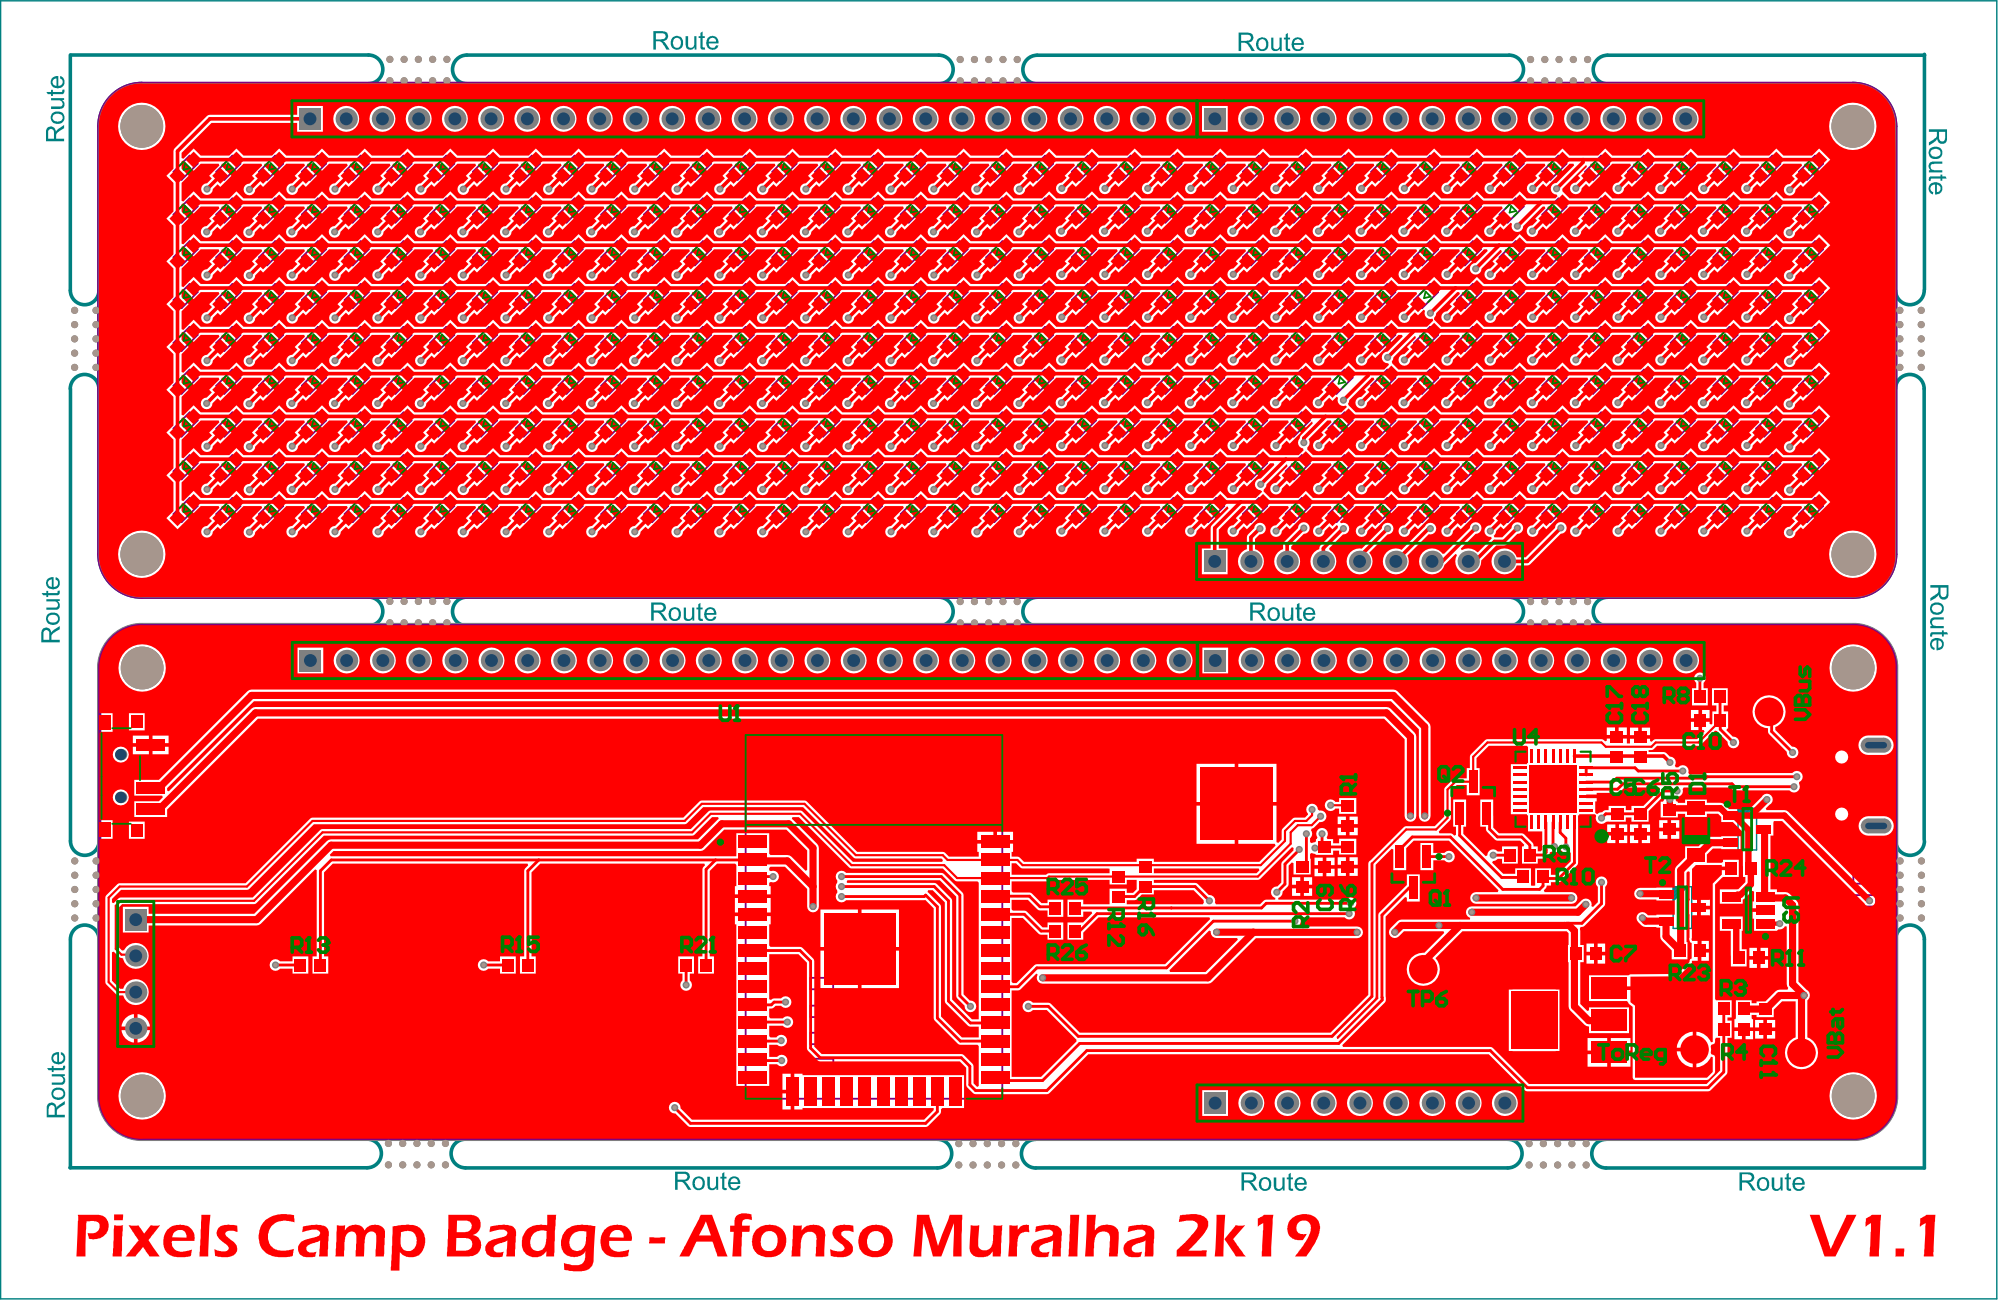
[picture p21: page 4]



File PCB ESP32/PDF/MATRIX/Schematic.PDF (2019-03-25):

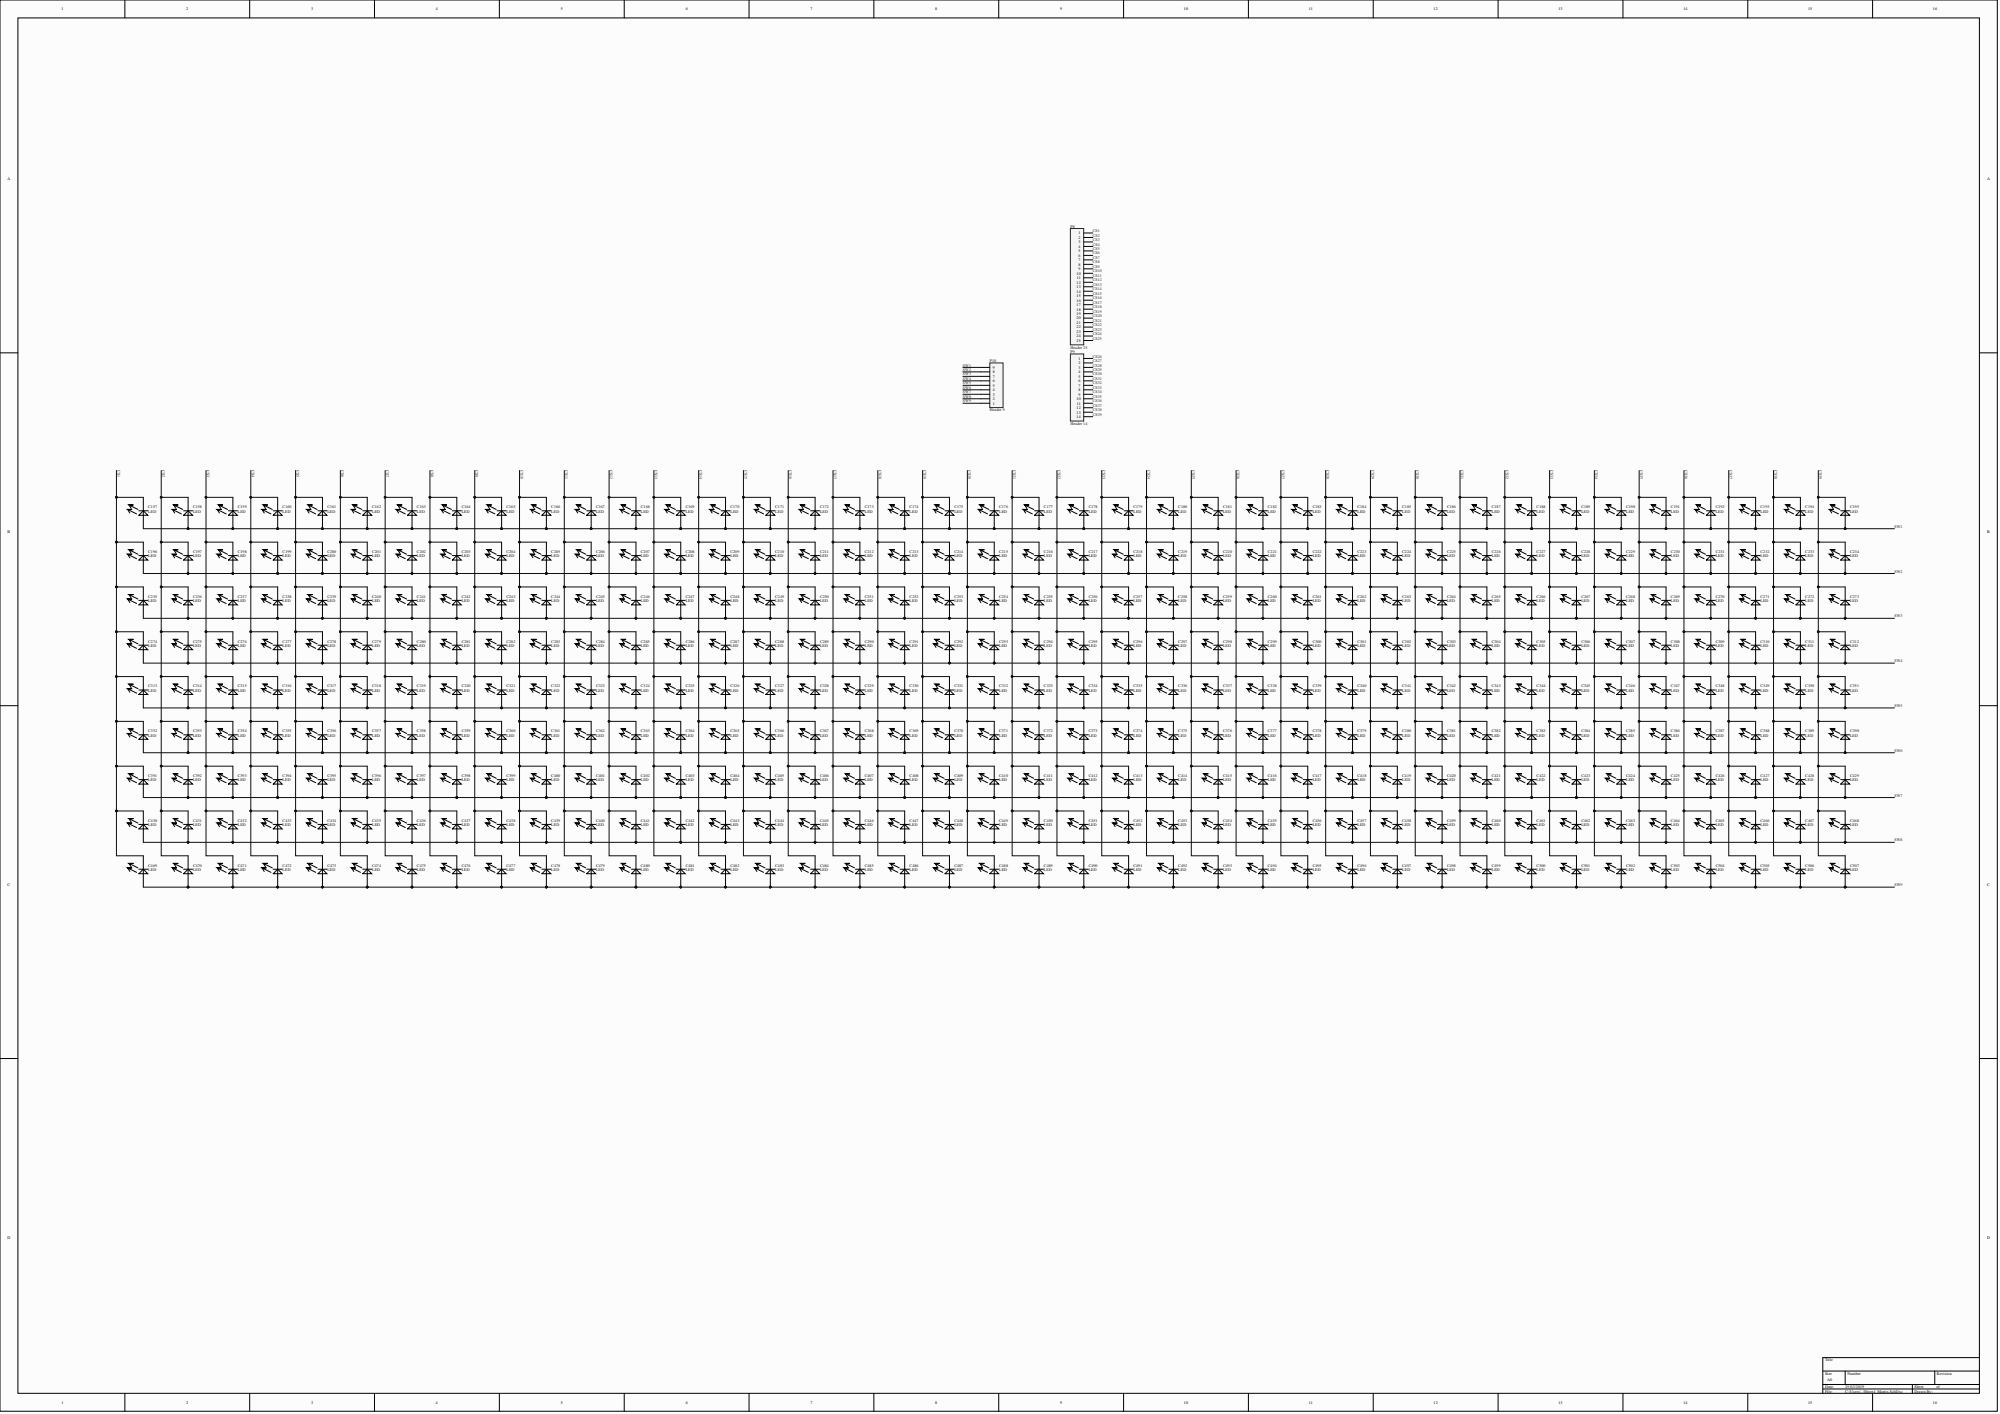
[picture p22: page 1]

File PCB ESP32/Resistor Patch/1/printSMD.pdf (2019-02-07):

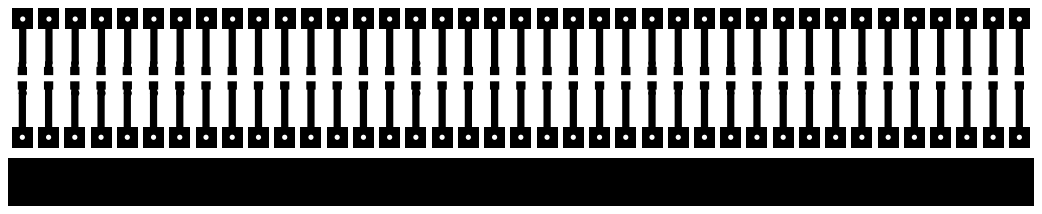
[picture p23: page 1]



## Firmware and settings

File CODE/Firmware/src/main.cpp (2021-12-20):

#include "../include/main.h"


//#include <ESPmDNS.h>

char *ssid = "Pixels Camp Badger";
char *password = "1234567890";

extern void initMatrix();
extern void vMatrixTask();
extern int initWebServer();
extern String ip_addr;
extern SemaphoreHandle_t xStringSemaphore;
extern String textRX;

TaskHandle_t xHandleMatrixTask;

void idleLedTask( void * parameter )
{
  // textScroll();
}

void BtnReadTask( void * parameter )
{
  for(;;){
    uint8_t state = 000;
    state = (digitalRead(SWLEFT) << 2) | (digitalRead(SWCENTER) << 1 ) | (digitalRead(SWRIGHT));
    // Serial.print("Button state: "); Serial.println(digitalRead(SWLEFT));
    if(!digitalRead(SWLEFT)){
      textRX = ip_addr;
      xSemaphoreGive(xStringSemaphore);
    }
    delay(500);
  }

}

void idleLedTask2( void * parameter )
{
  for(;;){
  digitalWrite(LED1, HIGH);
  digitalWrite(LED2, HIGH);
  digitalWrite(LED3, HIGH);
  digitalWrite(LED4, HIGH);
  delay(500);
  digitalWrite(LED1, LOW);
  digitalWrite(LED2, LOW);
  digitalWrite(LED3, LOW);
  digitalWrite(LED4, LOW);
  delay(500);
  }
}

void createTasks(){
  // xTaskCreate(
  //                   I2CUnloadTask,          /* Task function. */
  //                   "I2CUnloadTask",        /* String with name of task. */
  //                   1000,            /* Stack size in bytes. */
  //                   NULL,             /* Parameter passed as input of the task */
  //                   6,                /* Priority of the task. */
  //                   NULL);  
  

  xTaskCreate(
                   BtnReadTask,          /* Task function. */
                   "BtnReadTask",        /* String with name of task. */
                   1000,            /* Stack size in bytes. */
                   NULL,             /* Parameter passed as input of the task */
                   4,                /* Priority of the task. */
                   NULL);
  // xTaskCreate(
  //                  idleLedTask2,          /* Task function. */
  //                  "idleLedTask2",        /* String with name of task. */
  //                  configMINIMAL_STACK_SIZE,            /* Stack size in bytes. */
  //                  NULL,             /* Parameter passed as input of the task */
  //                  5,                /* Priority of the task. */
  //                  NULL);

  // xTaskCreateUniversal (
  //                  vMatrixTask,          /* Task function. */
  //                  "MatrixTask",        /* String with name of task. */
  //                  10000,            /* Stack size in bytes. */
  //                  NULL,             /* Parameter passed as input of the task */
  //                  0 | portPRIVILEGE_BIT ,                /* Priority of the task. */
  //                  &xHandleMatrixTask,
  //                  0);
}


void setup()
{
  Serial.begin(115200);
  // vTaskSuspendAll();
  initSPIFFS();
  initIO();
  initMatrix();
  // vTaskDelay(1000);
  // textScroll();
  initWifi(ssid, password, !digitalRead(SWLEFT)); 
  initWebServer();
  
  createTasks();
  // vTaskResume(xHandleMatrixTask);
}

void loop()
{
  // Serial.print("Battery Voltage: "); Serial.println(batVoltage());
  // delay(500);
  // String inString;
  // xQueueReceive(xStringQueue, &inString, portMAX_DELAY);
  // Serial.print(inString);
  vMatrixTask();
}

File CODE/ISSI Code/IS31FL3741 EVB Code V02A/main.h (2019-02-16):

/**
  ******************************************************************************
  * @file    main.h
  * $Author: wdluo $
  * $Revision: 67 $
  * $Date:: 2012-08-15 19:00:29 +0800 #$
  * @brief   主函数包含的头文件.
  ******************************************************************************
  * @attention
  *
  *<h3><center>&copy; Copyright 2009-2012, ViewTool</center>
  *<center><a href="http:\\www.viewtool.com">http://www.viewtool.com</a></center>
  *<center>All Rights Reserved</center></h3>
  * 
  ******************************************************************************
  */
/* Define to prevent recursive inclusion -------------------------------------*/
#ifndef __MAIN_H
#define __MAIN_H
/* Includes ------------------------------------------------------------------*/

#define R_LED 0
#define G_LED 1
#define B_LED 2

#define SCAL 0
#define PWM  1

#define Mode_Max 4

/*choose IC promgram*/
#define VERSION 1

#if  VERSION==1
#include "IS31FL3741.h"
#elif VERSION==2
#include "IS31FL3742.h"
#endif

#endif/* __MAIN_H */

/*********************************END OF FILE**********************************/

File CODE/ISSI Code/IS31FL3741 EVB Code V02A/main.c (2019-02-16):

/* Includes ------------------------------------------------------------------*/
#include "stm32f10x.h"
#include "main.h"

volatile u8 Mode_NO = 1;

int main(void)
{
	Set_System();
	I2C_GPIO_Init();
	USB_Interrupts_Config();//	
	Set_USBClock();//
	USB_Init();//
	EXTI_PB0_Config();
	#if  VERSION==1
	IS31FL3741_Init();
	#elif VERSION==2
	IS31FL3742_Init();
	#endif
	while(1)	
	{
		#if  VERSION==1
 		Play_IS31FL3741_Demo_mode();
		#elif VERSION==2
		Play_IS31FL3742_Demo_mode();
		#endif
	}
}

/*********************************END OF FILE**********************************/

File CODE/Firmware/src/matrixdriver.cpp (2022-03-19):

#include "../lib/ISSI/LEDMatrixDriver.hpp"

#include <Arduino.h>
#include "../include/boardpins.h"
#include "bitmaps.h"
#define byte uint8_t

#include "../lib/AdafruitGFX/Fonts/Tiny3x3a2pt7b.h"

#define XSIZE 9
#define YSIZE 39

SemaphoreHandle_t xI2CSemaphore;
LEDMatrixDriver matrix(MATRIX_SDA, MATRIX_SCL, MATRIX_ADDR_GND, MATRIX_EN);
SemaphoreHandle_t xStringSemaphore;

String textRX = "Pixels Camp Badger!";
String text;
int spacing = 3;
int speed = 50;
int brightness = 40;

// void I2CUnloadTask( void * parameter ){
//     // xSemaphoreTake( xI2CSemaphore,
//     //              portMAX_DELAY);
//     // matrix.unloadI2CBuffer();
//     for(int i = 0; i<39; i++)
//         for(int j = 0; j<9; j++)
//             matrix.writePixelLow(j, i, 0x3);
// }

void initMatrix(){
    xStringSemaphore = xSemaphoreCreateBinary();
    Serial.print("Initializing Matrix...");
    
    // xI2CSemaphore = xSemaphoreCreateBinary();
    // xSemaphoreTake( xI2CSemaphore,
    //              portMAX_DELAY);


    // vTaskSuspendAll();

    matrix.begin();
    matrix.setEnabled(1);
    // matrix.setTextSize(2);
    
    // matrix.setFont(&Tiny3x3a2pt7b);
    Serial.print("Done!\n");
    return;

    // for(int i = 0; i<39; i++)
    //     for(int j = 0; j<9; j++)
    //         matrix.writePixelLow(j, i, 0x3);
    // matrix.writePixelLow(2, 2, 0x3);

    // matrix.setPixel(3, 3, 0x3);

    // matrix.drawCircle(4, 4, 4, 0xA);
    // matrix.drawCircle(14, 4, 4, 0xA);
    // matrix.drawCircle(24, 4, 4, 0xA);
    // matrix.drawCircle(34, 4, 4, 0xA);

    // matrix.drawBitmap(0, 0, glasses, 39, 9, 0xE);


    // matrix.setTextColor(0xE, 0x00);
    // matrix.setCursor(7, 1);
   


}

void matrixPrintString(int x){
    matrix.fillScreen(0);
    matrix.print("abcd");
    matrix.updateFrameBuffer();

}

void setBrightness(int brightness){
    matrix.setTextColor(map(brightness, 0, 100, 0, 255));
    matrix.updateFrameBuffer();
}

void vMatrixTask(){
    
    int string_len;
    int text_x = 0; // Initial text position = off right edge
    int text_y = 1;
    int text_min;
    uint16_t w, h;
    int16_t ignore;
    int max_strings;
    int matrix_width = matrix.width();
    int x_positions[10];
    int x_positions_init[10];
    int i;
    int spawn_position;
    portBASE_TYPE xStatusQ;

    // String text = "The quick brown fox jumps over the lazy dog ";   // A message to scroll
    
    // xSemaphoreTake( xStringSemaphore, portMAX_DELAY );
    Serial.println(textRX);


    text = "";
    text = textRX;
    for(i=0;i<spacing;i++)
        text += " ";
    matrix.setTextColor(brightness);
    matrix.fillScreen(0);
    matrix.updateFrameBuffer();
    // return;
    string_len = text.length();
    text_x = 0; // Initial text position = off right edge
    text_y = 1;
    matrix.setTextWrap(false);

    // Get text dimensions to determine X coord where scrolling resets
    
    matrix.getTextBounds(text, 0, 0, &ignore, &ignore, &w, &h);
    // Serial.print("Text size: "); Serial.println(w);
    max_strings = (matrix.width() / w) + 2;
    // Serial.println(max_strings);

    for(i = 0; i<max_strings; i++){
        x_positions[i] = (w*i);//+matrix_width;
        x_positions_init[i] = (w*i);//+matrix_width;
    }
    spawn_position = (max_strings-1)*w;

    while(1){
        xStatusQ = xSemaphoreTake( xStringSemaphore, 1 );
        if(xStatusQ == pdTRUE){
            text = "";
            text = textRX;
            for(i=0;i<spacing;i++)
                text += " ";
            Serial.println(text);
            matrix.setTextColor(brightness);
            matrix.fillScreen(0);
            matrix.updateFrameBuffer();
            // return;
            string_len = text.length();
            text_x = 0; // Initial text position = off right edge
            text_y = 1;
            matrix.setTextWrap(false);

            // Get text dimensions to determine X coord where scrolling resets
            
            matrix.getTextBounds(text, 0, 0, &ignore, &ignore, &w, &h);
            // Serial.print("Text size: "); Serial.println(w);
            max_strings = (matrix.width() / w) + 2;
            // Serial.println(max_strings);
    
            for(i = 0; i<max_strings; i++){
                x_positions[i] = (w*i);//+matrix_width;
                x_positions_init[i] = (w*i);//+matrix_width;
            }
            spawn_position = (max_strings-1)*w;
        }
        else{
            matrix.fillScreen(0);
            matrix.updateFrameBuffer();
            
            for(i = 0; i<max_strings; i++){
                matrix.setCursor(x_positions[i], text_y);
                matrix.print(text); // write the letter
                --x_positions[i];
            }
            for(i = 0; i<max_strings; i++){
                if(x_positions[i] == -w){
                    x_positions[i] = spawn_position;
                }
            }
            matrix.setTextColor(brightness);
            matrix.updateFrameBuffer();
            delay(speed);
        }
    
    }
    
    

    // while(1){
        
    //     // delay(70);
    // }
}

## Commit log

2018-09-09 half of the matrix done
    [Matrix.PrjPcb, PCB1.PcbDoc, Sheet1.SchDoc]
2018-09-10 matrix schematic and component placement done
    [PCB1.PcbDoc, Sheet1.SchDoc]
2018-09-10 lost work :( but recovered
    [Matrix.PrjPcb, PCB1.PcbDoc, Sheet1.SchDoc]
2018-09-10 done routing
    [PCB1.PcbDoc]
2018-09-13 started working on the main board
    [Matrix.PrjPcb, Sheet2.SchDoc]
2018-09-14 organized everything into subprojects
    [Control_Board.PrjPcb, Main.PrjPcb, Matrix.PrjPcb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]
2018-09-14 started power supply design and splited design into multiple sheets
    [Conns.SchDoc, Main.PrjPcb, NCP1450ASN27T1G.PcbLib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]
2018-09-29 i dunno
    [Conns.SchDoc, PCB2.PcbDoc, Sheet1.SchDoc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]
2019-01-10 doubled the matrix size, changed driver ic, not charlieplexed anymore :(
    [Conns.SchDoc, Control_Board.PcbDoc, Control_Board.PrjPcb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]
2019-01-11 tested boards layout, tested panel
    [Conns.SchDoc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]
2019-01-13 did more routing, exported pdfs, started working on the silkscreen
    [Control_Board.GBL, Control_Board.GBO, Control_Board.GBP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]
2019-01-13 more silkscreening
    [Control_Board.PcbDoc]
2019-01-14 finished routing, made new panels
    [Control_Board.GBL, Control_Board.GBO, Control_Board.GBP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]
2019-01-14 edited silkscreen
    [Control_Board.GBL, Control_Board.GBO, Control_Board.GBP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]
2019-01-22 exported pdfs, edited readme
    [Control_Board.PcbDoc, Control_Board.PrjPcb, PCB2.PcbDoc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]
2019-01-24 fixed some design flaws
    [Control_Board.PcbDoc, Sheet2.SchDoc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]
2019-01-25 fixed errors, updated readme, added patch board
    [Conns.SchDoc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]
2019-01-26 edited control board, added power supply switching simulation
    [Control_Board.PcbDoc, Control_Board.PrjPcb, Sheet2.SchDoc]
2019-01-26 random changes, edited readme
    [Sheet2.SchDoc]
2019-02-07 test code, layout and route, readme
    [Control_Board.PcbDoc, PCB1.PcbDoc, ResistorPatch1.PcbDoc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]
2019-02-08 readme, code
    [ResistorPatch1.PcbDoc, SOT223_Patch.PrjPCB, Sheet2.SchDoc]
2019-03-08 Changes to software, minor changes to pcb
2019-03-10 Started working on the led driver code
2019-03-22 Matrix driver works!
2019-03-25 added schematics, edited readme
2019-09-18 Added Writeup files
    [Control_Board.PcbDoc, PCB2.PcbDoc]
2019-09-20 Added led driver resistors. Removed old regulator. Replaced usb do serial IC. Some layout and routing.
    [Control_Board.PcbDoc, Control_Board.PrjPcb, Sheet2.SchDoc]
2019-09-21 Layout. New silkscreen design.
    [Control_Board.PcbDoc, Sheet2.SchDoc, bot_silkV2.dxf]
2019-09-30 Fixed shutdown pin allways on. Did pre-final routing and planning.
    [Control_Board.PcbDoc, Sheet2.SchDoc, panel.PcbDoc]
2019-10-03 Auto stash before merge of "master" and "origin/master"
    [Sheet2.SchDoc]
2019-10-05 Added new silkscreen. PCBway logo missing
    [Control_Board.PcbDoc]
2019-10-07 New usb footprint, final finishes
    [Control_Board.PcbDoc, Control_Board.PrjPcb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]
2019-10-08 Exported final v1.1 boards
    [Control_Board.GBL, Control_Board.GBO, Control_Board.GBP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]
2019-10-08 Minor changes
    [Panel.PrjPCB]
2019-10-08 edited usb port. submitted to fb review
    [Control_Board.PcbDoc, Panel.PrjPCB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]
2019-10-09 Fixed control board gerbers
    [Control_Board.PcbDoc, Sheet2.SchDoc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]
2019-10-25 Fab Files and BOM
    [BOM.xls, Control_Board.PcbDoc, Control_Board.PcbLib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]
2019-12-01 USB footprint was not changed on schematic for some reason???
    [Sheet2.SchDoc]
2020-01-18 Started working on v2.1 (2.0fix)
    [Sheet2.SchDoc]
2020-01-18 Finished routing
    [Control_Board.PrjPcb]
2020-01-18 Re-did the silkscreen. Added variants for the silkscreen (no-branding and pcbway branding), edited output job, fixed DRC errors
    [Control_Board.GBL, Control_Board.GBO, Control_Board.GBP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]
2020-02-23 Final touches, exported control board gerbers and sent to fab
    [Control_Board.GBL, Control_Board.GBO, Control_Board.GBP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]
2020-03-27 updated bom and pdf of the control board
    [BOM.xls]
2020-03-27 Minor changes to the firmware. Tested on new board, works!
2020-04-02 Updated configuration resistors for usb to uart bridge. Generated new pdfs and removed old ones
    [Sheet2.SchDoc]
2020-05-30 Fixed enable. Misc changes. Working on new hardware version
    [boardpins.h, main.cpp, matrixdriver.cpp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]
2020-05-31 fixed errors, need testing
    [matrixdriver.cpp]
2020-06-01 Matrix lib low level functionality working
    [C232HM.cfg]
2020-06-06 Added modified wire library to the project
2020-06-06 framebuffer working
2021-12-20 Fixed push button pins, implemented wifi boot modes and ip printing. Updates to webUI
    [boardpins.h, main.cpp, wifip.cpp]
2021-12-20 fixed ip printing when on wifi AP mode
    [wifip.cpp]
2022-03-23 Added usb-c
    [Sheet2.SchDoc]
